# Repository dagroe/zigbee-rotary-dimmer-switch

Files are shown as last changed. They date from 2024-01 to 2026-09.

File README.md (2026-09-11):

# A rotary Zigbee dimmer switch
A Zigbee dimmer switch with a tactile feeling like classic rotary dimmers that seamlessly integrates with your existing switch and socket design lines (e.g. Gira System 55).

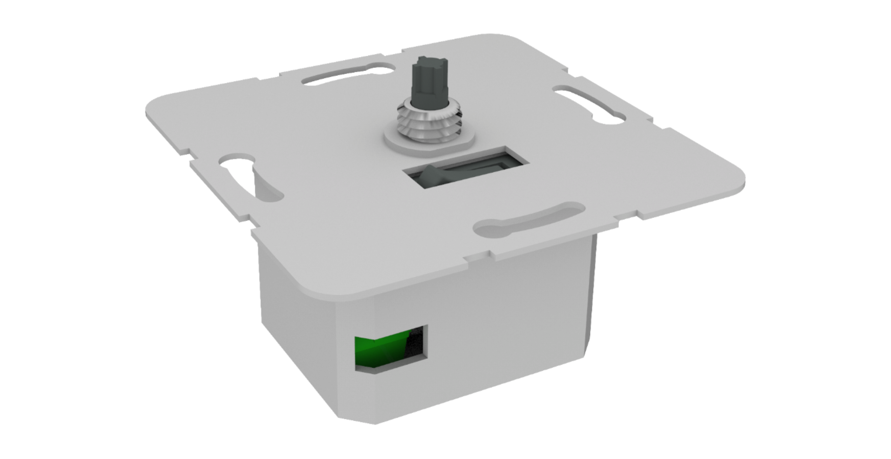
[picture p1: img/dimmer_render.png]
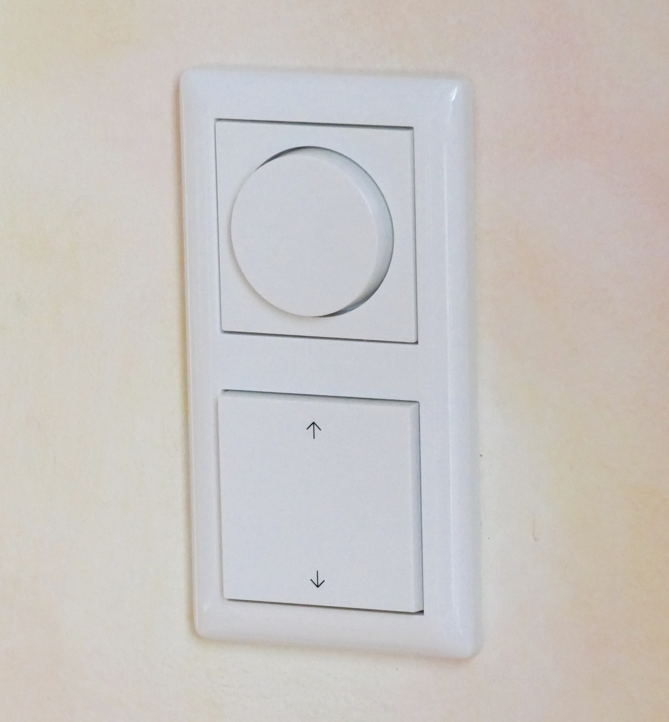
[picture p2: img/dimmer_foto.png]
|   |   |
|---|---|

## Use case, requirements, and features
The goal of this dimmer switch is to
* provide tactile feeling like classic rotary dimmers, i.e. rotate and push one big knob (instead of multiple buttons)
* integrate with existing switch and socket design lines (e.g. Gira System 55), also for multi frames
* offer an optional 230V (or 110V) power supply, no more changing batteries + acts as Zigbee router
* control existing smart lights (e.g. Philips Hue), not making classic bulbs smart (i.e. switching/dimming classic bulbs)

Also nice to have:
* be extendable, e.g. easily add multiple dimmer switches or push buttons in multi frames
* ✅ allow for a second rotary input by rotating the knob while pushing it (e.g. to change color temperature or scenes) — _implemented: push + rotate changes color temperature_
* ✅ feature an integrated 230V (or 110V) mechanical switch to switch power of the connected lamp socket (e.g. for emergencies or to reset the lamp when replacing classic wall switches) — _implemented: on-board relay + dedicated button_
* be affordable

## Backstory: Why yet _another_ Zigbee dimmer switch?
TL;DR; I couldn't find one to fit my use case, so I decided to build my own.

When I moved into my new home I already had many Philips Hue Bulbs and classic Hue dimmer switches (the on with the four buttons) to control the lights.
However, those didn't integrate well with my Gira System 55 outlets, switches, frames, etc. even when using fancy adapters (https://www.samotech.co.uk/products/philips-hue-dimmer-frame-cover-light-switch/)
And I was also a big fan of using a rotary knob for dimming lights, since it is just more convenient.

So why didn't I use available rotary zigbee dimmers? Basically all dimmers I found are "real" dimmers, in the sense that they expect to control a load (classic dimmable bulb) or simply don't fit into the 55mm Gira system.

Since I though "well, it can't be that hard to hook up a rotary encoder to a Zigbee chip", I set out to build a rotary dimmer switch myself.

## Current state of development
A working second prototype is built around the **ESP32-C6**. It joins any standard Zigbee coordinator (zigbee2mqtt, Home Assistant ZHA, deCONZ, …) as a mains-powered **Zigbee router** and controls bound smart lights with a single rotary knob. Hardware, firmware, and enclosure design files are all in this repository. It is a DIY prototype, not a finished product — see [Help wanted](#help-wanted).

### Hardware
- **ESP32-C6-MINI** module (Zigbee/Thread radio), programmed/powered over USB-C.
- Integrated **230V → 5V** power supply (IRM-02-5S) plus a 3.3V regulator — no batteries, and it acts as a Zigbee router.
- **Rotary encoder with push** (the single "big knob") for dimming and on/off.
- **WS2812B RGB LED** for status/feedback.
- On-board **230V relay** (on a normally-closed contact) to switch the connected lamp socket directly, with a dedicated button to toggle it.
- A separate commissioning button for pairing / factory reset.
- Two **external daughterboard ports** so the in-wall module can drive a second control surface: a port for an external rotary encoder (a second dimmer) and a port for a plain wall switch. Both are optional — when nothing is wired in they idle and stay unused.
- Designed to fit **Gira System 55** frames.

### Controls
| Input | Action |
| ----- | --- |
| Rotate knob | Brightness up / down (bound lights) |
| Push knob — short tap | Toggle on / off |
| Push knob — hold | Off |
| Push **and** rotate | Color temperature (warm / cool) |
| Relay button — tap | Cut / restore the 230V outlet (works even with no network) |
| External encoder (optional) | Second, independently bindable dimmer — same controls as the knob |
| External wall switch (optional) | Toggle on / off for its own independently bound light |
| Commission button — tap | Pair (start network steering) |
| Commission button — hold ~5 s | Factory reset (yellow warning while holding, red on reset) |

LED feedback: green = joined · solid red = not connected · white blink = command sent · red blink = command dropped (not joined) · blue blink = relay toggled · yellow = pairing / reset warning.

### Firmware
Built with **ESP-IDF** and the **esp-zigbee-sdk**. From `firmware/`:
```
idf.py set-target esp32c6
idf.py build
idf.py -p <PORT> flash monitor
```
After the first flash, firmware updates are delivered **over the air** (standard Zigbee OTA, with automatic rollback of a bad image). The single source of truth for the version is `firmware/main/version.h`.

### Repository layout
- `hardware/` — KiCad schematics, PCB, and exported gerbers/3D models.
- `firmware/` — ESP-IDF project ([`firmware/docs/OTA.md`](firmware/docs/OTA.md), [`firmware/z2m/README.md`](firmware/z2m/README.md), `firmware/TODO.md`).
- `enclosure/` — printable enclosure / knob design files.

## zigbee2mqtt integration & over-the-air updates
The dimmer joins any standard Zigbee coordinator and exposes four endpoints: the on-board **controller** (endpoint 1) that sends on/off, brightness and color commands to bound lights, the on-board **230V relay** (endpoint 2) to switch the connected lamp socket directly, and the two optional daughterboard ports — an **external encoder** (endpoint 3, a second dimmer) and an **external wall switch** (endpoint 4). Each controller endpoint is bound independently, so they act as separate controllers sharing one device card. It also implements the standard Zigbee OTA Upgrade cluster, so firmware updates are delivered over the air. To add the device to zigbee2mqtt and receive OTA updates from this repo, follow [`firmware/z2m/README.md`](firmware/z2m/README.md). Firmware-side OTA details (partitioning, rollback) are in [`firmware/docs/OTA.md`](firmware/docs/OTA.md).

## Help wanted
My prototype is working but I see a lot of potential for improvement. Since I am mostly a software engineer with limited knowledge of electronics, I am looking for other interested in taking this project further. You can find me on discord here: https://discord.gg/CjbDc5nPja or checkout the discussion here: https://community.home-assistant.io/t/diy-zigbee-rotary-wall-dimmer/681751

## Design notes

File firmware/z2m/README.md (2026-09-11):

# Using the dimmer with zigbee2mqtt (incl. OTA updates)

This folder is the zigbee2mqtt integration for the **DG Electronics ESP32-C6
rotary dimmer** (`ESP_DIMMER_1`):

| File | Purpose |
| ---- | --- |
| `ESP_DIMMER_1.js` | External converter — makes z2m recognize the device and enables OTA. |
| `ota-index.json` | OTA index served to z2m so it auto-discovers firmware updates. |
| `images/*.ota` | Published firmware images referenced by the index. |

The device speaks the **standard ZCL OTA Upgrade cluster**, so this also works
with ZHA/deCONZ — they just consume `ota-index.json` differently.

### What the device exposes

| Endpoint | Role | Use |
| --- | ---- | --- |
| 1 (`controller`) | on-board encoder/button: sends on/off, level (brightness) and color commands | Bind it to your light(s) via the device's **Bind** tab, or use the emitted commands in automations. |
| 2 (`relay`) | on/off **output** for the on-board 230V relay | Switch the connected lamp socket directly (e.g. emergency cut-off) from HA/z2m. |
| 3 (`ext_encoder`) | external encoder daughterboard: a **second dimmer** (on/off, level, color) | Bind it **independently** to a different light/group — so one in-wall module drives two dimmers. Unused if no board is connected. |
| 4 (`ext_switch`) | external **wall switch**: plain on/off (toggle) controller | Bind it independently to its own light/group. Unused if no switch is connected. |

> Endpoints 3 and 4 are always present. Because each endpoint is bound
> separately, the external encoder and switch act as independent controllers
> sharing the one device card — the closest a single Zigbee node gets to
> "separate devices". If nothing is wired to the daughterboard ports, those
> endpoints simply stay unbound and idle.

## Install (zigbee2mqtt users)

1. **Add the external converter.** Download
   [`ESP_DIMMER_1.js`](https://raw.githubusercontent.com/dagroe/zigbee-rotary-dimmer-switch/main/firmware/z2m/ESP_DIMMER_1.js)
   into your z2m **data directory** (next to `configuration.yaml`), and reference it:

   ```yaml
   external_converters:
     - ESP_DIMMER_1.js
   ```

2. **Enable OTA from this repo.** Point z2m at the hosted index — no download
   needed, z2m fetches it:

   ```yaml
   ota:
     zigbee_ota_override_index_location: https://raw.githubusercontent.com/dagroe/zigbee-rotary-dimmer-switch/main/firmware/z2m/ota-index.json
   ```

3. **Restart z2m.** The device now shows as *DG Electronics / ESP_DIMMER_1*, and
   the device's **OTA** tab will offer an update whenever a newer image is
   published here. (z2m checks on a schedule and the device also asks hourly;
   you can also click **Check for update** to force it.)

That's it — future firmware updates arrive over the air, no reflashing.

## Releasing a new firmware (maintainers)

The version lives only in `firmware/main/version.h`. To cut a release:

```bash
cd firmware

# 1. bump FW_VERSION_* in main/version.h, then build
idf.py build

# 2. package the image AND update the index in one step
python tools/make_ota.py \
    --in build/light_switch.bin \
    --out z2m/images/dimmer-<MAJOR.MINOR.PATCH>.ota \
    --index z2m/ota-index.json

# 3. commit the new image + index and push to main
git add z2m/images/dimmer-<MAJOR.MINOR.PATCH>.ota z2m/ota-index.json
git commit -m "OTA: release firmware <MAJOR.MINOR.PATCH>"
git push origin main
```

`make_ota.py` reads the version/manufacturer/image-type from the firmware
headers, computes `fileSize`/`sha512`, and rewrites the matching `ota-index.json`
entry with the raw-GitHub `url` for the new image. Once pushed to `main`, every
user's z2m discovers it automatically.

> The raw URLs above point at the **`main`** branch, so the integration only
> works once these files are merged to `main`.

See [`../docs/OTA.md`](../docs/OTA.md) for how the OTA client, partitioning, and
rollback work on the firmware side.

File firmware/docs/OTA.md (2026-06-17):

# Over-the-air firmware updates (Zigbee OTA)

The firmware implements the **standard ZCL OTA Upgrade cluster (0x0019)** as a
client. The device advertises a manufacturer code, image type, and the version
it is currently running; the coordinator (zigbee2mqtt, Home Assistant ZHA,
deCONZ, …) acts as the OTA server and pushes a matching `.ota` image. Nothing in
this is vendor-specific — any compliant coordinator can update the device.

## How matching works

A coordinator only offers an image when **all** of these hold:

| Field | Firmware source | Default |
| --- | --- | --- |
| Manufacturer code | `OTA_UPGRADE_MANUFACTURER` (`main/ota_driver.h`) | `0x131B` (4891)|
| Image type | `OTA_UPGRADE_IMAGE_TYPE` (`main/ota_driver.h`) | `0x1010` (4112)|
| File version | `FW_VERSION_*` (`main/version.h`) | `1.0.x` → `0x010000xx` |

The image's header manufacturer code + image type must equal the firmware's, and
its file version must be **greater** than the running version.

## Releasing an update

The version lives in exactly one place — `main/version.h` — and feeds the OTA
file version, the SW Build ID z2m shows, the ESP-IDF app version, and the `.ota`
the packaging script produces.

1. Bump `FW_VERSION_MAJOR/MINOR/PATCH` in `main/version.h` (e.g. `1.0.3` → `1.0.4`).
2. `idf.py build` — produces `build/light_switch.bin`.
3. Package the `.ota` (version/manufacturer/image-type are read from the headers,
   so no numbers to pass):

   ```
   python tools/make_ota.py --in build/light_switch.bin --out dimmer.ota
   ```

   The script prints the `fileVersion`, `fileSize`, and `sha512` to drop into the
   z2m index below.

## Serving it to zigbee2mqtt

Users install the device + auto-OTA by adding the external converter and the
hosted OTA index — see **[`../z2m/README.md`](../z2m/README.md)**. As a
maintainer you publish a release by pointing `make_ota.py` at `z2m/ota-index.json`
(it writes the image into `z2m/images/` and updates the index with the raw-GitHub
`url`), then commit + push to `main`; every user's z2m then discovers it.

For a quick local test without GitHub, you can instead point z2m's
`ota.zigbee_ota_override_index_location` at a local `ota-index.json` whose `url`
is a path z2m can read (in Docker, the in-container path), or use z2m's manual
"upload firmware" button to push a `.ota` directly.

## Rollback (auto-revert of a bad update)

App-rollback is enabled (`CONFIG_BOOTLOADER_APP_ROLLBACK_ENABLE`). A freshly
OTA'd image boots in *pending-verify* state and is only confirmed once the device
**rejoins the network** (`ota_confirm_running_image()` from the steering-success
signal). If the new image instead crashes or wedges before rejoining, the task
watchdog reboots it and the bootloader reverts to the previous working image. So
an update that bricks Zigbee self-heals without a site visit.

Implication for releases: the new firmware must be able to join the network, or
it will be rolled back. A normally-booted (UART-flashed) image is never in
pending-verify, so this is a no-op outside of OTA.

## First-time / verification notes

- On first OTA, watch the `OTA` log tag: `download started`, periodic writes, then
  `OTA complete (... bytes). Rebooting`. After reboot the device rejoins, logs
  `New OTA image confirmed healthy`, and reports the new `fileVersion`.
- To test rollback: build an image that deliberately fails to join, OTA it, and
  confirm the device reverts to the previous version after the watchdog reboot.
- The two app slots are `ota_0`/`ota_1` (1.5 MB each) from the dual-OTA partition
  table; an image must fit in one slot.

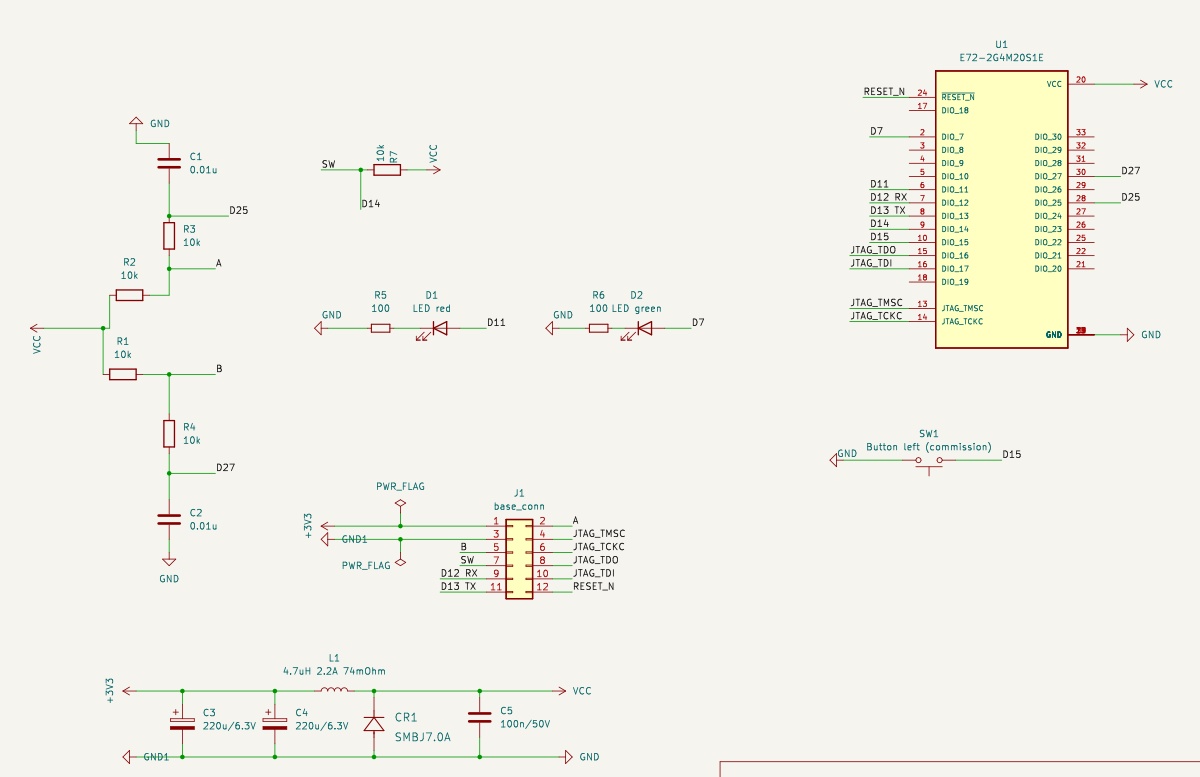
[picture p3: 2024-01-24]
img/dimmer_front_schematics.png

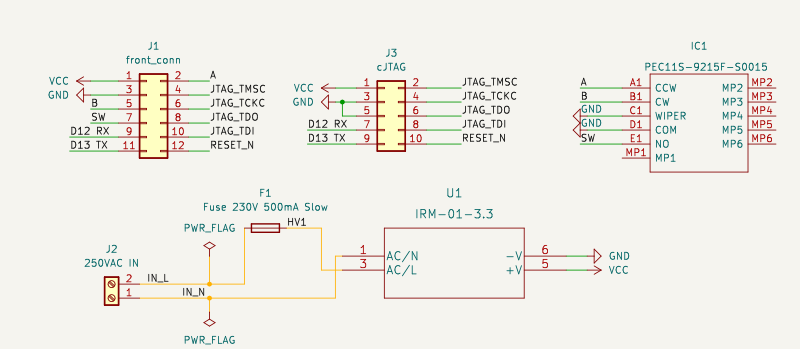
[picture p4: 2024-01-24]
img/dimmer_base_schematics.png

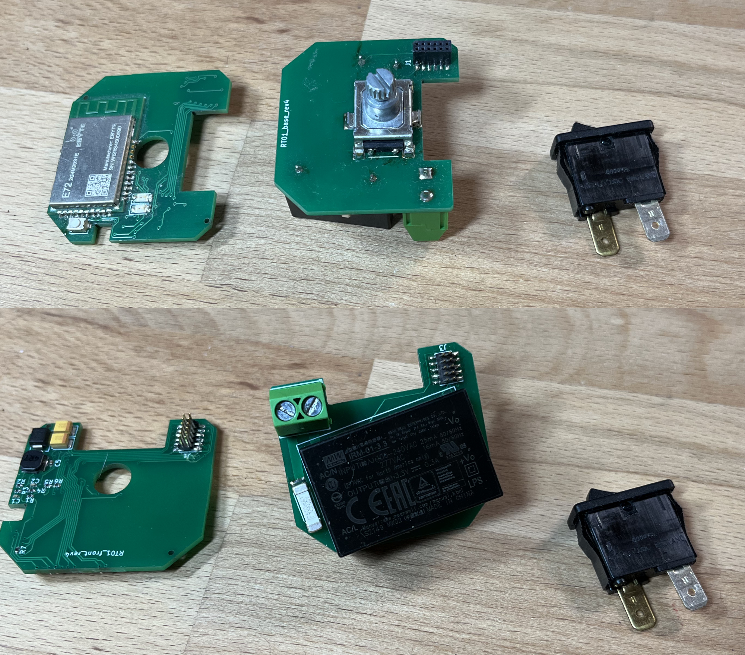
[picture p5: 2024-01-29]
img/dimmer_2.jpg

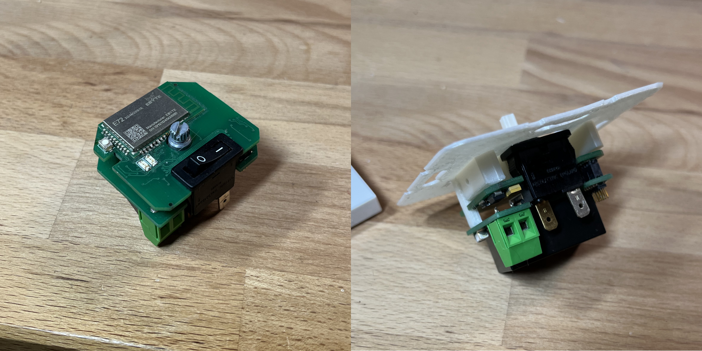
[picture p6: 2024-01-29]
img/dimmer_5.jpg

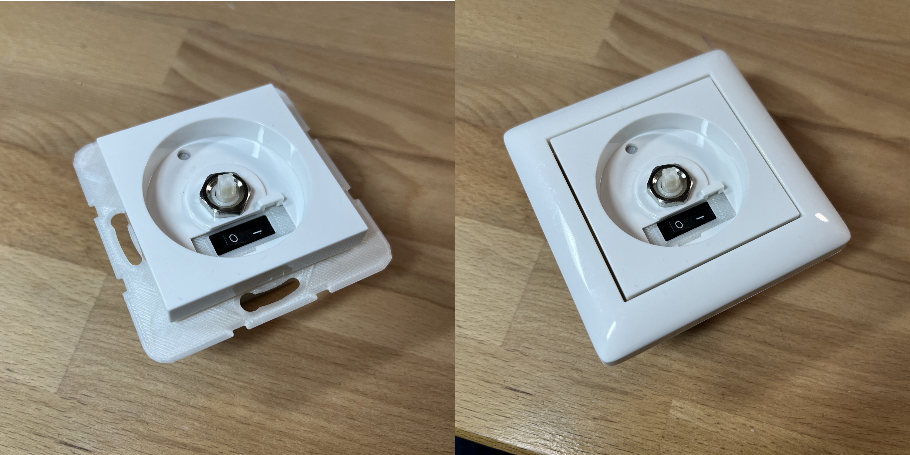
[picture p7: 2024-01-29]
img/dimmer_4.jpg

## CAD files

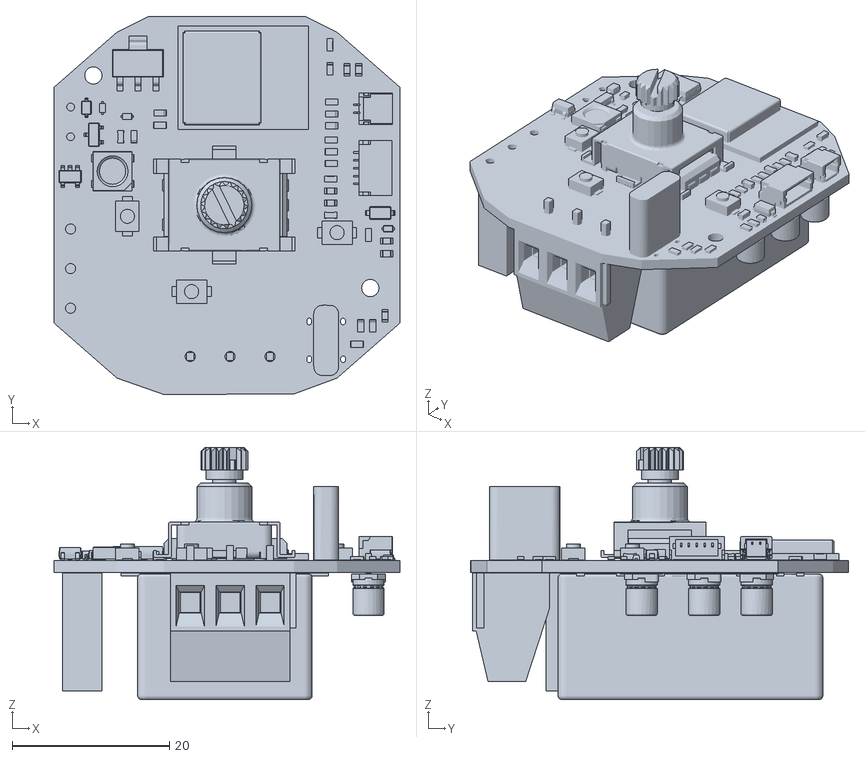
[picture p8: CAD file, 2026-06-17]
hardware/3d/dimmer_esp_v2_main.stl
44.0 x 48.1 x 32.1

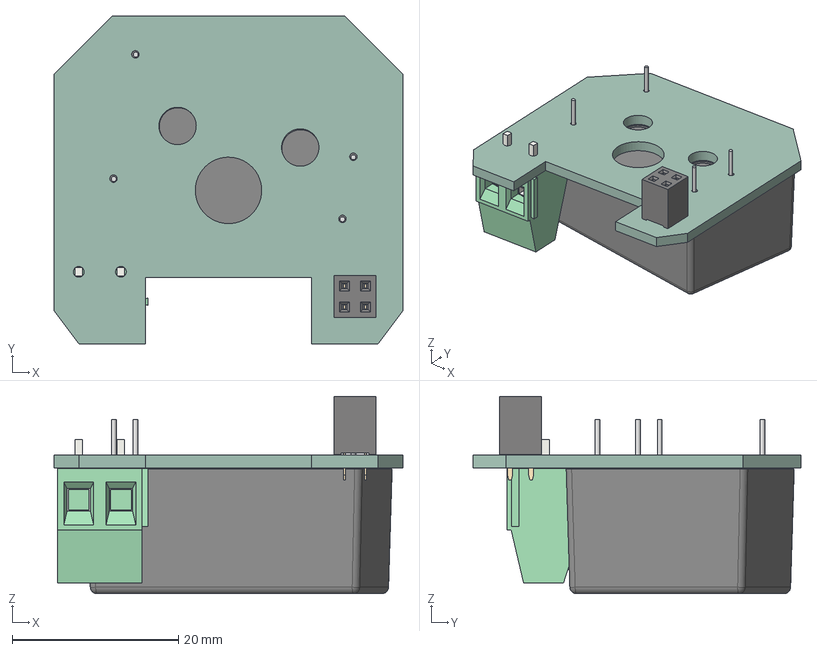
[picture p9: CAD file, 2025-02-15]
hardware/3d/dimmer_esp_v1_4_power230.step
42.0 x 39.5 x 23.8 mm
PinSocket_2x02_P254mm_Vertical
TerminalBlock_Phoenix_MKDS_15_2_508_1x02_P508mm_Horizontal
ASSEMBLY
IRM-01-5
dimmer_esp_v1_power230_PCB

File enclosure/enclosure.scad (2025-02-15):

$fa = 1;
$fs = 0.2;



make_shaft = true;
make_base_plate = true;
make_spacer = true;
make_middle_spacer = true;
build_bottom_shell = true;
render_top_pcb = false;
render_bottom_pcb = false;

include <BOSL2/std.scad>
include <BOSL2/threading.scad>

// function for rounded rectangle
module make_rounded_rectangle(width, height, radius) {
    hull() {
        translate([radius,radius,0]) circle(radius);
        translate([width-radius,radius,0]) circle(radius);
        translate([width-radius,height-radius,0]) circle(radius);
        translate([radius,height-radius,0]) circle(radius);
    }
}

// main function to make front facing plate with thread/bushing
module base_plate(thickness, width_and_depth, corner_radius, offset_z) {
    // make cutouts into plate

    // make for holes with circular slits to attach base plate to wall socket
    // prepare rectangular cutouts on border (will be rotated to four sides along other holes)
    cutout_depth_x = 1.5;
    cutout_width_y = 4.15;
    cutout_offset_y = 19.8;

    distance_from_border = 3.7;
    length_hole_in_arc_degree = 25;
    width_hole = 3.7;
    width_bigger_hole = 5.5;
    arc_offset = width_hole * 0.5;

    radius_circle = width_and_depth*0.5 - distance_from_border - arc_offset;

    difference(){
        // make solid plate first
        linear_extrude(height=thickness) translate([-width_and_depth*0.5, -width_and_depth*0.5, 0]) make_rounded_rectangle(width_and_depth, width_and_depth, corner_radius);

        // make cutouts on 4 sides
        for (i=[0:1:4]) {
            center = i * 360 / 4;

            // holes for screws
            rotate([0, 0, center-length_hole_in_arc_degree/2]) rotate_extrude(angle=length_hole_in_arc_degree,convexity = 10) translate([radius_circle, 0,0]) square(width_hole, center=true);
            rotate([0, 0, center+length_hole_in_arc_degree/2]) linear_extrude(5, center=true) translate([radius_circle, 0, 0]) circle(d=width_bigger_hole);
            rotate([0, 0, center-length_hole_in_arc_degree/2]) linear_extrude(5, center=true) translate([radius_circle, 0, 0]) circle(d=width_hole);

            // hole markers on sides
            rotate([0, 0, center]) translate([width_and_depth*0.5 - cutout_depth_x, cutout_offset_y*0.5+cutout_width_y*0.5, 0]) translate([0, -cutout_width_y*0.5, 0]) linear_extrude(20, center=true) square([cutout_depth_x, cutout_width_y]);
            rotate([0, 0, center]) translate([width_and_depth*0.5 - cutout_depth_x, -(cutout_offset_y*0.5+cutout_width_y*0.5), 0]) translate([0, -cutout_width_y*0.5, 0]) linear_extrude(20, center=true) square([cutout_depth_x, cutout_width_y]);

        }

        // cutout rectangle for switch
        switch_cutout_width = 18.0;
        switch_cutout_depth = 7.0;
        switch_cutout_offset_y = -16.2;
        translate([0, switch_cutout_offset_y, 0]) linear_extrude(thickness+2, center=true) square([switch_cutout_width, switch_cutout_depth], center=true);
    }
}


// make custom shaft
shaft_length_encoder_connector = 8;
shaft_length_below_button_disc = 5.6;
// TOD add offset for disc from bottom / split bottom into half-shaft connector and full-shaft
shaft_length_top = 20;
shaft_length = shaft_length_encoder_connector + shaft_length_below_button_disc + shaft_length_top;
shaft_diameter_top = 4.0;
shaft_radius_top = shaft_diameter_top/2;
shaft_diameter_encoder_connector = 3.1;
shaft_radius_encoder_connector = shaft_diameter_encoder_connector/2;
shaft_encoder_connector_cut_offset_y = 0.3;

disc_height = 1;
disc_diameter = 6;
disc_radius = disc_diameter/2;

shaft_4mm_part_length = shaft_length_below_button_disc + shaft_length_top;


if(make_shaft) {

translate([0,0,0]) color([1,0,0]) union() {
    // make top shaft part (4mm diameter)
    translate([0,0,shaft_length_encoder_connector+shaft_4mm_part_length/2]) cylinder(h=shaft_4mm_part_length, r=shaft_radius_top, center=true);
    // make disc that pushes on the button
    translate([0,0,shaft_length_encoder_connector+shaft_length_below_button_disc+(disc_height/2)]) cylinder(h=disc_height, r=disc_radius, center=true);
    // make encoder connector (cut off half the shaft for "D" shape)
    difference() {
        translate([0,0,shaft_length_encoder_connector/2]) cylinder(h=shaft_length_encoder_connector, r=shaft_radius_encoder_connector, center=true);
        translate([-(shaft_radius_encoder_connector+1), shaft_encoder_connector_cut_offset_y, -1]) cube([shaft_diameter_encoder_connector+2, shaft_radius_encoder_connector+1, shaft_length_encoder_connector+2]);
    }
}
}

flap_thickness = 0.8;

spacer_height = 2.6 + flap_thickness; //2.6
cutter_height = spacer_height + 2;


// make spacer between base plate and top pcb that also stabilizes the push ring
if(make_spacer) {
    translate([0,0,10.2]) color([0,0,1]) {
        union() {
        difference() {
            // base rectangle
            translate([0,4,0]) linear_extrude(height=spacer_height) square([29.6,25], center=true);
            // subtract first hole for encoder clamp
            translate([6,0,cutter_height/2-1]) cylinder(h=cutter_height, r=1.5, center=true);
            // subtract second for encoder clamp
            translate([-6,0,cutter_height/2-1]) cylinder(h=cutter_height, r=1.5, center=true);
            // subtract cutout for push disc
            //translate([0,0,cutter_height/2+1.8]) cylinder(h=cutter_height, r=11/2, center=true);
            // subtract cutout for button
            translate([0,4,-0.5]) linear_extrude(height=cutter_height) square([9.8,5], center=true);
            // subtract cutout for LED
            translate([-12,4.7,-0.5]) linear_extrude(height=cutter_height) square([8,8], center=true);
            // subtract cutout for buttons
            translate([-10,14.5,-0.5]) linear_extrude(height=cutter_height) square([14,12], center=true);
            // flap cutout
            translate([0,0,-1]) linear_extrude(height=spacer_height+2) square([9.8,12], center=true);
            // holes for encoder pins
            translate([0,-7.5,0]) cylinder(h=4, r=1, center=true);
            translate([0,-8.5,-2]) linear_extrude(height=4) square([2,2], center=true);
            translate([-2.54,-7.5,0]) cylinder(h=4, r=1, center=true);
            translate([-2.54,-8.5,-2]) linear_extrude(height=4) square([2,2], center=true);
            translate([2.54,-7.5,0]) cylinder(h=4, r=1, center=true);
            translate([2.54,-8.5,-2]) linear_extrude(height=4) square([2,2], center=true);
        }
        difference() {
            // make "flap"
            translate([0,-1,spacer_height-flap_thickness]) linear_extrude(height=flap_thickness) square([8.8,13.8], center=true);
            // subtract hole for shaft
            translate([0,0,cutter_height/2-1]) cylinder(h=cutter_height, r=shaft_radius_top+0.2, center=true);
        }
        // make pusher on flap
        translate([0,4,spacer_height-flap_thickness-0.2]) linear_extrude(height=0.2) square([5,3], center=true);
       
        }
    }
    
}
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

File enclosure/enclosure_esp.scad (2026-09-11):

$fa = 1;
$fs = 0.2;
$fn=64;



make_shaft = false;
make_base_plate = true;
make_base_plate_thread = false;
make_thread = true;
make_spacer = true;
make_middle_spacer = true;
build_bottom_shell = false;
render_pcb = false;

include <BOSL2/std.scad>
include <BOSL2/threading.scad>

//translate([0.3,-0.8,0]) import(file="esp_edge_cuts3.svg",center=true);

/*
points = [
[181.5000,39.0000],
[189.5000,46.0000],
[189.5000,76.0000],
[181.5000,83.0000],
[172.0000,86.5000],
[163.5000,86.5000],
[153.5000,83.0000],
[145.5000,76.0000],
[145.5000,46.0000],
[153.5000,39.0000],
[157.5000,37.0000],
[177.5000,37.0000]
];

paths = [[0,1,2,3,4,5,6,7,8,9,10,11,0]];

difference() {
translate([-180,0,0]) linear_extrude(20) offset(1) polygon(points=points, paths=paths);
translate([-180,0,-1]) linear_extrude(22) polygon(points=points, paths=paths);
}
*/

module my_model() {

    // function for rounded rectangle
    module make_rounded_rectangle(width, height, radius) {
        hull() {
            translate([radius,radius,0]) circle(radius);
            translate([width-radius,radius,0]) circle(radius);
            translate([width-radius,height-radius,0]) circle(radius);
            translate([radius,height-radius,0]) circle(radius);
        }
    }

    // main function to make front facing plate with thread/bushing
    module base_plate(thickness, width_and_depth, corner_radius, offset_z) {
        // make cutouts into plate

        // make for holes with circular slits to attach base plate to wall socket
        // prepare rectangular cutouts on border (will be rotated to four sides along other holes)
        cutout_depth_x = 1.5;
        cutout_width_y = 4.15;
        cutout_offset_y = 19.8;

        distance_from_border = 3.7;
        length_hole_in_arc_degree = 25;
        width_hole = 3.7;
        width_bigger_hole = 5.5;
        arc_offset = width_hole * 0.5;

        radius_circle = width_and_depth*0.5 - distance_from_border - arc_offset;

        difference(){
            // make solid plate first
            linear_extrude(height=thickness) translate([-width_and_depth*0.5, -width_and_depth*0.5, 0]) make_rounded_rectangle(width_and_depth, width_and_depth, corner_radius);

            // make cutouts on 4 sides
            for (i=[0:1:4]) {
                center = i * 360 / 4;

                // holes for screws
                rotate([0, 0, center-length_hole_in_arc_degree/2]) rotate_extrude(angle=length_hole_in_arc_degree,convexity = 10) translate([radius_circle, 0,0]) square(width_hole, center=true);
                rotate([0, 0, center+length_hole_in_arc_degree/2]) linear_extrude(5, center=true) translate([radius_circle, 0, 0]) circle(d=width_bigger_hole);
                rotate([0, 0, center-length_hole_in_arc_degree/2]) linear_extrude(5, center=true) translate([radius_circle, 0, 0]) circle(d=width_hole);

                // hole markers on sides
                rotate([0, 0, center]) translate([width_and_depth*0.5 - cutout_depth_x, cutout_offset_y*0.5+cutout_width_y*0.5, 0]) translate([0, -cutout_width_y*0.5, 0]) linear_extrude(20, center=true) square([cutout_depth_x, cutout_width_y]);
                rotate([0, 0, center]) translate([width_and_depth*0.5 - cutout_depth_x, -(cutout_offset_y*0.5+cutout_width_y*0.5), 0]) translate([0, -cutout_width_y*0.5, 0]) linear_extrude(20, center=true) square([cutout_depth_x, cutout_width_y]);

            }
        }
    }

    // socket adapter
    module SocketAdapter(side_thickness=1.0, shaft_radius=3.0, offset_z=0) {

        // ----- Parameters -----
        top_thickness       = 0.5;
        groove_margin       = 0.10;
        height              = 4 + 0.2; // knob height + margin
        thread_tunnel_margin= 0.2;
        thread_tunnel_length= 3.5;
        dial_connector_length = 4.2;
        margin_from_knob    = 0.2;
        overlap_bottom      = 0.1;
        knob_radius         = 3.0;

        // ----- Inner cutout -----
        module knob_socket_make_inner_cutout(knob_radius, margin_from_knob, height) {
            outer_r = knob_radius + margin_from_knob;
            inner_r = outer_r - 0.5;
            n = 36; // 2*18
            pts = [
                for (i = [0:n-1]) 
                    let (a = 360/n * i)
                    [(i % 2 == 0 ? inner_r : outer_r) * cos(a),
                     (i % 2 == 0 ? inner_r : outer_r) * sin(a)]
            ];
            linear_extrude(height)
                polygon(points=pts);
        }

        // ----- Outer shell -----
        module knob_socket_make_outer_shell(knob_radius, side_thickness, top_thickness, height) {
            difference() {
                cylinder(r=knob_radius+side_thickness, h=height+top_thickness, $fn=72);
            }
        }

        // ----- Groove -----
        module knob_socket_make_groove(shaft_radius, groove_width, groove_height, height) {
            width = shaft_radius*2-0.2;
            translate([-width/2, -groove_width/2, height-groove_height])
                cube([width, groove_width, groove_height], center=false);
        }

        // ----- Knob socket -----
        module make_knob_socket(knob_radius, shaft_radius, margin_from_knob, side_thickness, top_thickness, groove_margin, height) {
            groove_width  = 1 - groove_margin;
            groove_height = 1.6;
            
            union() {
                difference() {
                    knob_socket_make_outer_shell(knob_radius, side_thickness, top_thickness, height);
                    translate([0,0, -1]) knob_socket_make_inner_cutout(knob_radius, margin_from_knob, height + 1);
                }
                knob_socket_make_groove(shaft_radius, groove_width, groove_height, height);
            }
            
        }

        // ----- Shaft -----
        module make_shaft(height, top_thickness, shaft_radius, thread_tunnel_length, dial_connector_length, overlap_bottom) {
            overlap_top = 0.5;

            // Cross boxes
            box_width = 1;
            box_height = dial_connector_length+overlap_top;
            
            middle_radius = shaft_radius;

            union() {
                translate([0,0,-overlap_bottom]) cylinder(h=thread_tunnel_length+overlap_top+overlap_bottom, r=middle_radius);
                translate([0,0,thread_tunnel_length])
                union() {
                    translate([0,0,box_height/2]) cube([box_width, middle_radius*2 - 0.1, box_height], center=true);
                    translate([0,0,box_height/2]) cube([middle_radius*2 - 0.1, box_width, box_height], center=true);
                    cylinder(r=2.05, h=dial_connector_length+overlap_top);
               };
            }
            
        }
        


        // ----- Build adapter -----
        translate([0,0, offset_z - (height + top_thickness)])
            union() {
                make_knob_socket(knob_radius, shaft_radius, margin_from_knob, side_thickness, top_thickness, groove_margin, height);
                translate([0,0,height+top_thickness-overlap_bottom])
                     make_shaft(height, top_thickness, shaft_radius, thread_tunnel_length, dial_connector_length, overlap_bottom);
            }
            
    }

    pcb_outline_svg_offset_x = 0.3;
    pcb_outline_svg_offset_y = -0.8;

    side_thickness = 0.9;
        
    // socket adapter, thread tunnel cutout, and spacer
    shaft_diameter = 6.0;
    shaft_radius = shaft_diameter / 2;

    offset_z = 2;

    if (make_shaft) {
        color([1,0,0]) translate([0,0,-1.5]) SocketAdapter(side_thickness, shaft_radius, offset_z);
        
    }


    // base plate parameters
    base_plate_thickness = 1.6;
    base_plate_width_and_depth = 71.0;
    base_plate_corner_radius = 6.0;



    //shell_height = shell_bottom_thickness + space_at_bottom_of_shell + height_of_pcb_components_bottom + bottom_pcb_thickness + height_of_pcb_components_middle + top_pcb_thickness + space_between_top_pcb_and_base_plate;

    offset_base_plate = 0;//shell_height - shell_bottom_thickness - base_plate_thickness;

    top_rod_height = 7;

    reinforcement_ring_diameter = 14;
    reinforcement_ring_radius = reinforcement_ring_diameter / 2;
    reinforcement_ring_height = 1.2;

    base_plate_offset_z = -7;//13.6;


    //color([1,0,0]) translate([0,0,5]) cylinder(h=20, r=2.9, center=true);

    // shaft adapter
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

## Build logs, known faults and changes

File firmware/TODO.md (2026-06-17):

# Firmware TODO

Deferred robustness/maintainability items from the wall-install review.
Items are roughly in priority order.

## Smaller follow-ups

- [ ] **Re-add network-loss self-heal, safely.** A first attempt (re-steer on
  ESP_ZB_ZDO_SIGNAL_LEAVE / NO_ACTIVE_LINKS_LEFT) was reverted: it raced the
  stack's own commissioning/leave state machine — it broke initial joins
  (leave-with-rejoin during commissioning) and asserted in `zdo_app.c` during a
  coordinator-forced leave-reset while steering was retrying. The stack already
  auto-rejoins routers on transient loss. If re-added, prefer a clean
  `esp_restart()` on a RESET-type leave (let the device come up factory-new)
  rather than calling commissioning APIs from the leave handler, and test
  against a coordinator that actively removes the device.

- [ ] **Handle LED-strip init failure more gracefully.** If
  `led_strip_new_rmt_device` fails, `led_task` is never started and nothing
  drains `led_evt_queue`; senders use timeout 0 so it is harmless, but the
  device then runs with no status LED.

## Done (wall-install review, this branch)

- [x] Move commission button off strapping pin GPIO9 → GPIO23 (board rewired + firmware)
- [x] Move relay driver off strapping pin GPIO15 → GPIO2 (board rewired; not yet driven by firmware)
- [x] Lock cross-task Zigbee stack calls (fixes vPortExitCritical freeze)
- [x] Reboot on critical init failure instead of hanging
- [x] Bound the Zigbee stack-lock wait so UI tasks can't wedge
- [x] Enable task-watchdog panic for self-recovery on hang
- [x] Raise Zigbee task priority/stack
- [x] Keep GPIO ISRs in IRAM (no dropped edges during flash writes)
- [x] Debounce only the active button's interrupt
- [x] 4MB flash + dual-OTA partition layout
- [x] Standard Zigbee OTA Upgrade client (download/apply; see `docs/OTA.md`)
- [x] OTA rollback: image confirmed only after rejoining the network, else
      auto-reverts to the previous image
- [x] Single-source firmware version (`main/version.h`) feeding OTA version,
      SW Build ID, app version, and the .ota packaging tool
- [x] Suppress outbound commands when not joined; LED feedback on every command
      (white = sent, red = dropped/not joined)
- [x] Relay: NC inversion fix, local GPIO18 button, and configurable
      power_on_behavior (StartUpOnOff, NVS-persisted)
- [x] UX: push-rotate = color temperature; factory-reset warning; knob-push
      hold dead-zone fix

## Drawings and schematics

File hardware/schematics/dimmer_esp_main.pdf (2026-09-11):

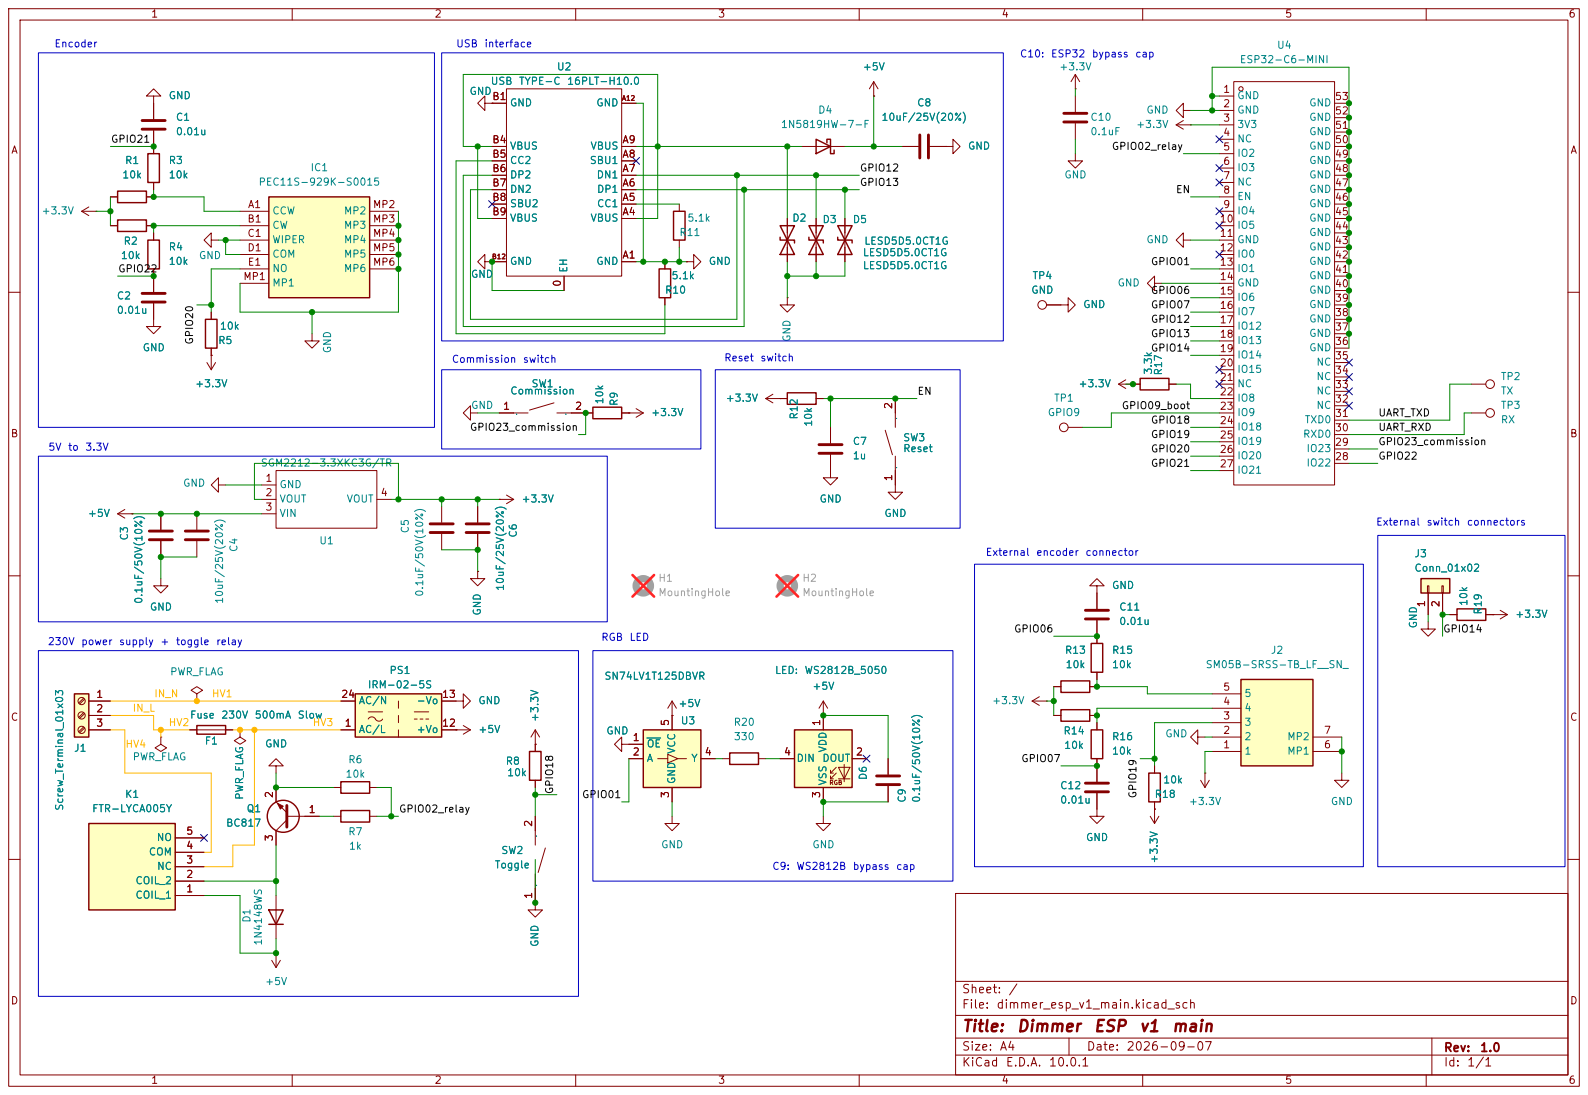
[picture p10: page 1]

VBUS A4 CC1 A5 DP1 A6 DN1 A7 SBU1 A8 VBUS A9 GND A12 GND B1

External switch connectors C9: WS2812B bypass cap RGB LED

230V power supply + toggle relay

Sheet: /
File: dimmer_esp_v1_main.kicad_sch
Title: Dimmer ESP v1 main

Size: A4 | Rev: 1.0
KiCad E.D.A. 10.0.1 | Id: 1/1

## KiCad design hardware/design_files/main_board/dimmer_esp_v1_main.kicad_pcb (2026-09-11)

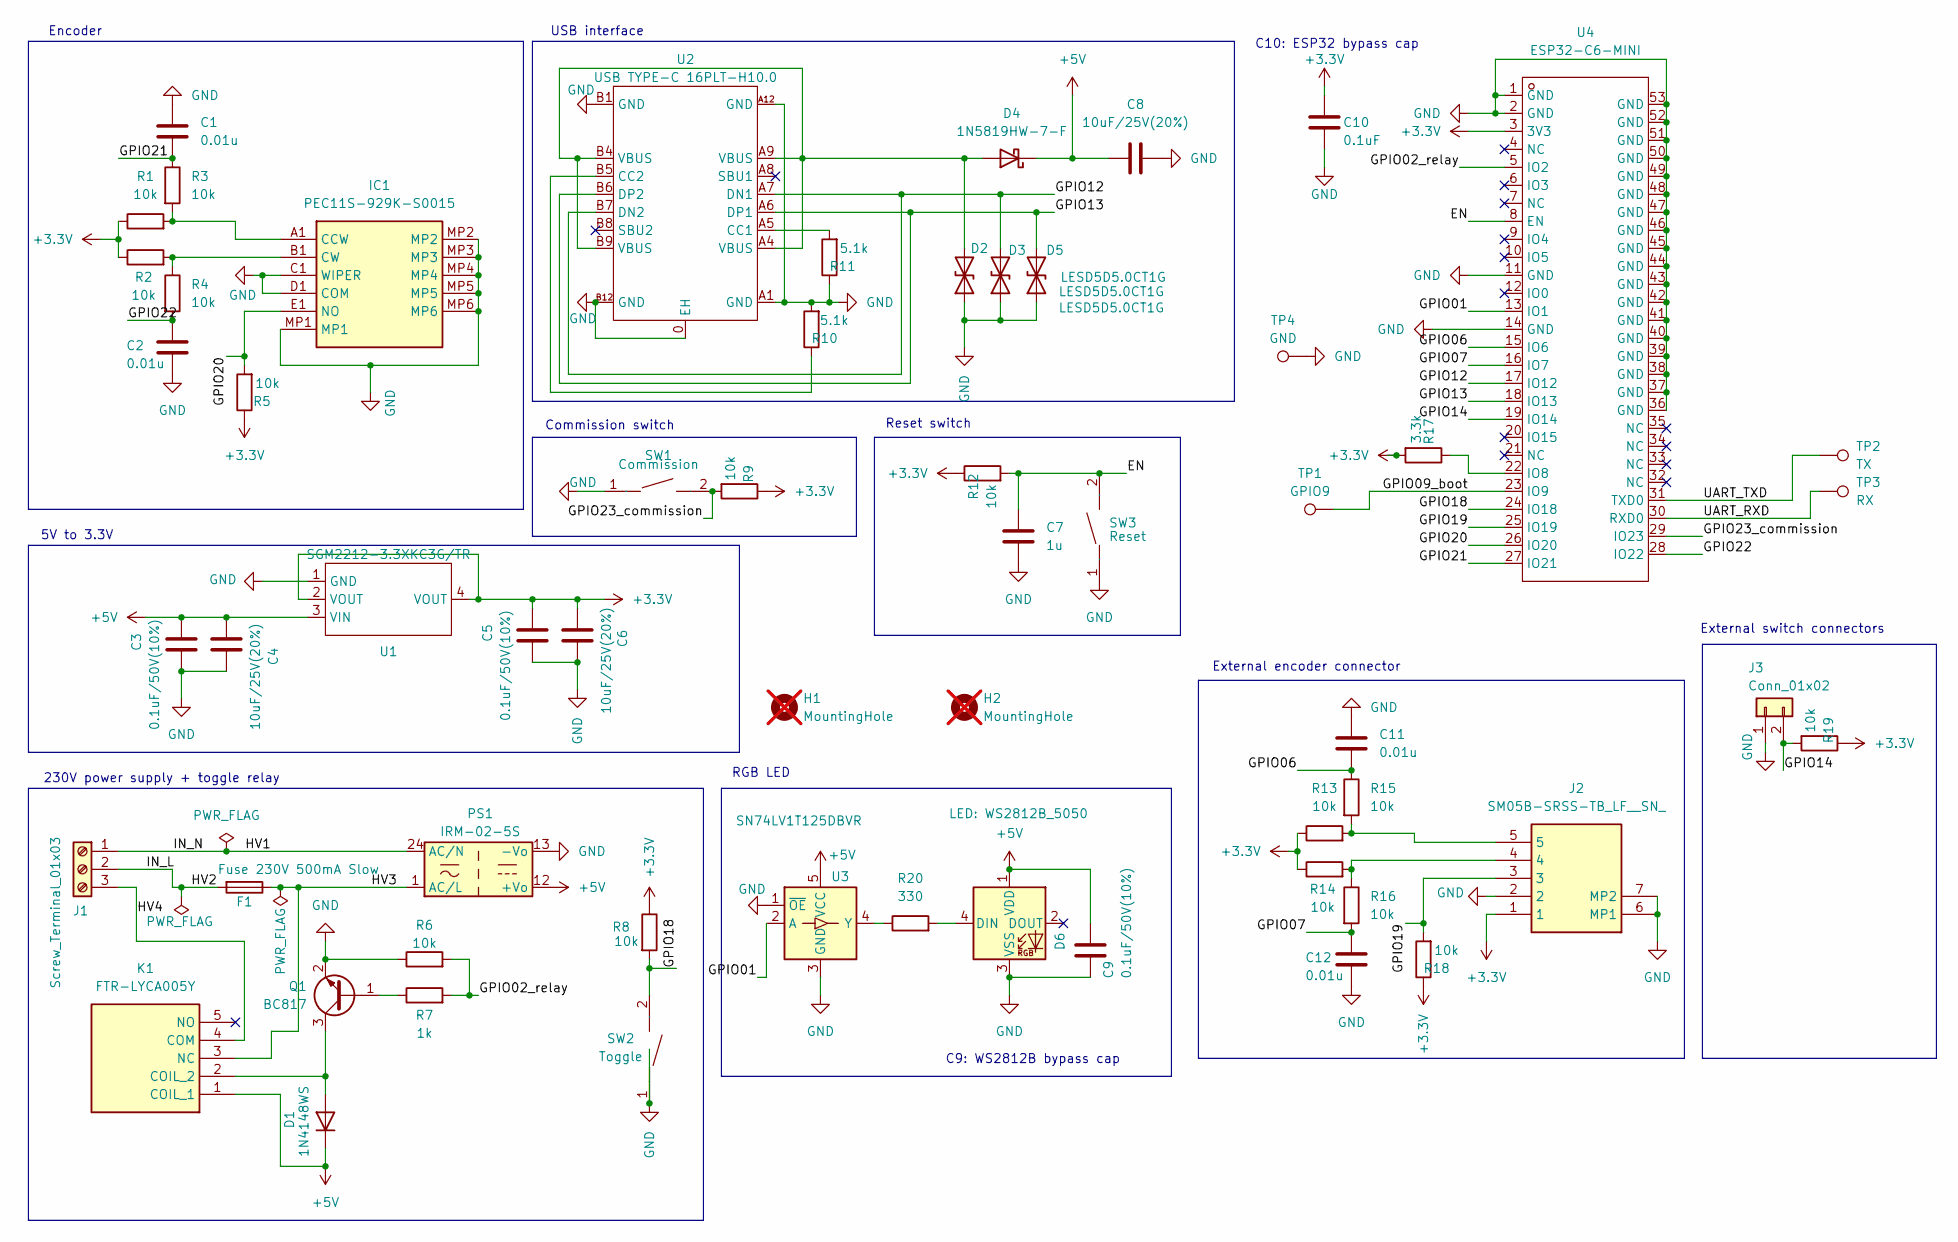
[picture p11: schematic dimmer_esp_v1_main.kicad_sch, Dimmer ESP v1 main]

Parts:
C1, C2, C11, C12: 0.01u; C_0603_1608Metric; MPN 0603B103K500NT; LCSC C57112
C3, C5: 0.1uF/50V(10%); C_0603_1608Metric; MPN CT41G-0603-2X1-50V-0.1uF-K(N); LCSC C125205
C4, C6, C8: 10uF/25V(20%); C_Elec_4x5.4; MPN MVK25V10M4*5 4.0TP; LCSC C371122
C7: 1u; C_0603_1608Metric; MPN CL10A105KB8NNNC; LCSC C15849
C9: 0.1uF/50V(10%); C_0603_1608Metric; LCSC C125205
C10: 0.1uF; C_0603_1608Metric; MPN CC0603KRX7R9BB104; LCSC C14663
D1: 1N4148WS; D_SOD-323; MPN 1N4148WS; LCSC C2128
D2, D3, D5: LESD5D5.0CT1G; D_SOD-523; MPN BNLESD5D5.0CT1G; LCSC C20416613
D4: 1N5819HW-7-F; D_SOD-123; MPN 1N5819HW-7-F; LCSC C82544
D6: LED: WS2812B_5050; LED_WS2812B_PLCC4_5.0x5.0mm_P3.2mm; MPN XL-5050RGBC-2812B; LCSC C2843785
F1: Fuse 230V 500mA Slow; 0443.500DR; MPN 0443.500DR; LCSC C315874
H1, H2: MountingHole; MountingHole_2.2mm_M2_DIN965; not fitted
IC1: PEC11S-929K-S0015; PEC11S929KS0015; Mouser Part Number 652-PEC11S929K-S0015
J1: Screw_Terminal_01x03; TerminalBlock_Phoenix_MKDS-1,5-3-5.08_1x03_P5.08mm_Horizont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; MPN 1715734; LCSC C480520
J2: SM05B-SRSS-TB_LF__SN_; JST_SH_SM05B-SRSS-TB_1x05-1MP_P1.00mm_Horizontal; Manufacturer_Part_Number SM05B-SRSS-TB(LF)(SN); LCSC C136657
J3: Conn_01x02; JST_SH_SM02B-SRSS-TB_1x02-1MP_P1.00mm_Horizontal; MPN SM02B-SRSS-TB(LF)(SN); LCSC C160402
K1: FTR-LYCA005Y; FTRLYCA024Y; Mouser Part Number 817-FTR-LYCA005Y
PS1: IRM-02-5S; Converter_ACDC_MeanWell_IRM-02-xx_SMD; MPN IRM-02-5S; LCSC C7211217
Q1: BC817; SOT-23; MPN BC817-40,215; LCSC C52801
R1, R2, R3, R4, R5, R6, R8, R9, R12, R13, R14, R15, R16, R18, R19: 10k; R_0603_1608Metric; MPN 0603WAF1002T5E; LCSC C25804
R7: 1k; R_0603_1608Metric; MPN 0603WAF1001T5E; LCSC C21190
R10, R11: 5.1k; R_0603_1608Metric; MPN 0603WAF5101T5E; LCSC C23186
R17: 3.3k; R_0603_1608Metric; MPN 0603WAF3301T5E; LCSC C22978
R20: 330; R_0603_1608Metric; MPN 0603WAF3300T5E; LCSC C23138
SW1: Commission; SW-SMD_L3.9-W3.0-P4.45; Manufacturer Part TS-1088-AR02016; LCSC Part Name 4*3*2mm 立贴 轻触开关
SW2: Toggle; SW-SMD_L3.9-W3.0-P4.45; Manufacturer Part TS-1088-AR02016; LCSC Part Name 4*3*2mm 立贴 轻触开关
SW3: Reset; SW-SMD_L3.9-W3.0-P4.45; Manufacturer Part TS-1088-AR02016; LCSC Part Name 4*3*2mm 立贴 轻触开关
TP1: GPIO9; TestPoint_Pad_D1.5mm
TP2: TX; TestPoint_Pad_D1.5mm
TP3: RX; TestPoint_Pad_D1.5mm
TP4: GND; TestPoint_Pad_D1.5mm
U1: SGM2212-3.3XKC3G/TR; SOT-223-3_L6.5-W3.4-P2.30-LS7.0-BR; Manufacturer Part SGM2212-3.3XKC3G/TR; LCSC Part Name SGM2212-3.3XKC3G/TR
U2: USB TYPE-C 16PLT-H10.0; TYPE-C-SMD_USB4120-03-C; Manufacturer Part TYPE-C 16PLT-H10.0; LCSC Part Name Type-C 母 立贴
U3: SN74LV1T125DBVR; SOT-23-5; MPN SN74LV1T125DBVR; LCSC C473338
U4: ESP32-C6-MINI; WIFIM-SMD_61P-L16.6-W13.2-P0.80-ESP32-C6-MINI-1-N4; Manufacturer Part ESP32-C6-MINI-1-N4; LCSC Part Name ESP32-C6-MINI-1-N4

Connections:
+3.3V: C5.2, C6.1, C10.1, J2.1, R1.1, R2.1, R5.1, R8.1, R9.1, R12.1, R13.1, R14.1, R17.2, R18.1, R19.1, U1.2 (VOUT), U1.4 (VOUT), U4.3 (3V3)
+5V: C3.2, C4.1, C8.1, C9.1, D1.1 (K), D4.1 (K), D6.1 (VDD), K1.1 (COIL_1), PS1.12 (+Vo), U1.3 (VIN), U3.5 (VCC)
/EN: C7.2, R12.2, SW3.2, U4.8 (EN)
/GPIO01: U3.2 (A), U4.13 (IO1)
/GPIO02_relay: R6.2, R7.2, U4.5 (IO2)
/GPIO06: C11.2, R15.1, U4.15 (IO6)
/GPIO07: C12.2, R16.2, U4.16 (IO7)
/GPIO09_boot: TP1.1 (1_1), U4.23 (IO9)
/GPIO12: D3.2 (A2), U2.A7 (DN1), U2.B7 (DN2), U4.17 (IO12)
/GPIO13: D5.2 (A2), U2.A6 (DP1), U2.B6 (DP2), U4.18 (IO13)
/GPIO14: J3.2, R19.2, U4.19 (IO14)
/GPIO18: R8.2, SW2.2, U4.24 (IO18)
/GPIO19: J2.3, R18.2, U4.25 (IO19)
/GPIO20: IC1.E1 (NO), R5.2, U4.26 (IO20)
/GPIO21: C1.2, R3.1, U4.27 (IO21)
/GPIO22: C2.2, R4.2, U4.28 (IO22)
/GPIO23_commission: R9.2, SW1.2, U4.29 (IO23)
/HV1: J1.1, PS1.24 (AC/N)
/HV2: F1.2, J1.2
/HV3: F1.1, K1.3 (NC), PS1.1 (AC/L)
/HV4: J1.3, K1.4 (COM)
/UART_RXD: TP3.1 (1_1), U4.30 (RXD0)
/UART_TXD: TP2.1 (1_1), U4.31 (TXD0)
GND: C1.1, C2.1, C3.1, C4.2, C5.1, C6.2, C7.1, C8.2, C9.2, C10.2, C11.1, C12.1, D2.1 (A1), D3.1 (A1), D5.1 (A1), D6.3 (VSS), IC1.C1 (WIPER), IC1.D1 (COM), IC1.MP1, IC1.MP2, IC1.MP3, IC1.MP4, IC1.MP5, IC1.MP6, J2.2, J2.6 (MP1), J2.7 (MP2), J3.1, PS1.13 (-Vo), Q1.2 (E), R6.1, R10.2, R11.1, SW1.1, SW2.1, SW3.1, TP4.1 (1_1), U1.1 (GND), U2.0 (EH), U2.A1 (GND), U2.A12 (GND), U2.B1 (GND), U2.B12 (GND), U3.1 (~OE), U3.3 (GND), U4.1 (GND), U4.2 (GND), U4.11 (GND), U4.14 (GND), U4.36 (GND), U4.37 (GND), U4.38 (GND), U4.39 (GND), U4.40 (GND), U4.41 (GND), U4.42 (GND), U4.43 (GND), U4.44 (GND), U4.45 (GND), U4.46 (GND), U4.47 (GND), U4.48 (GND), U4.49 (GND), U4.50 (GND), U4.51 (GND), U4.52 (GND), U4.53 (GND)
unnamed: D1.2 (A), K1.2 (COIL_2), Q1.3 (C)
unnamed: D2.2 (A2), D4.2 (A), U2.A4 (VBUS), U2.A9 (VBUS), U2.B4 (VBUS), U2.B9 (VBUS)
unnamed: D6.4 (DIN), R20.2
unnamed: IC1.A1 (CCW), R1.2, R3.2
unnamed: IC1.B1 (CW), R2.2, R4.1
unnamed: J2.4, R14.2, R16.1
unnamed: J2.5, R13.2, R15.2
unnamed: Q1.1 (B), R7.1
unnamed: R11.2, U2.A5 (CC1)
unnamed: R10.1, U2.B5 (CC2)
unnamed: R20.1, U3.4 (Y)
unnamed: R17.1, U4.22 (IO8)

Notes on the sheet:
RGB LED
External encoder connector
Encoder
USB interface
Commission switch
Reset switch
5V to 3.3V
C10: ESP32 bypass cap
C9: WS2812B bypass cap
External switch connectors
230V power supply + toggle relay

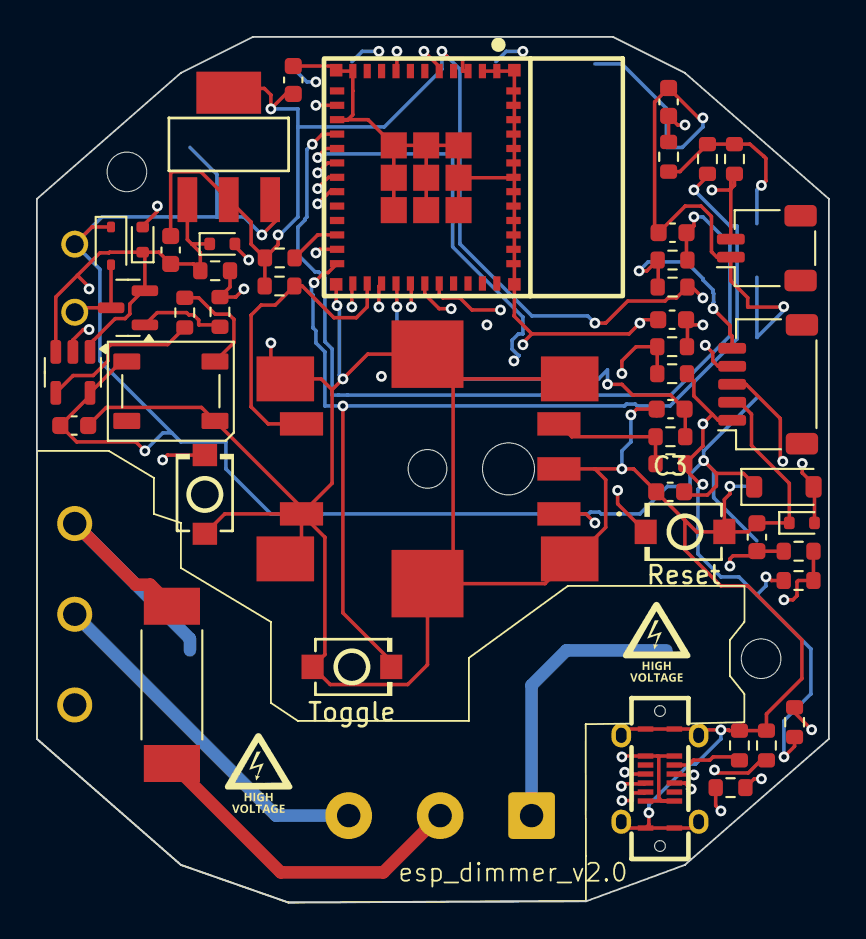
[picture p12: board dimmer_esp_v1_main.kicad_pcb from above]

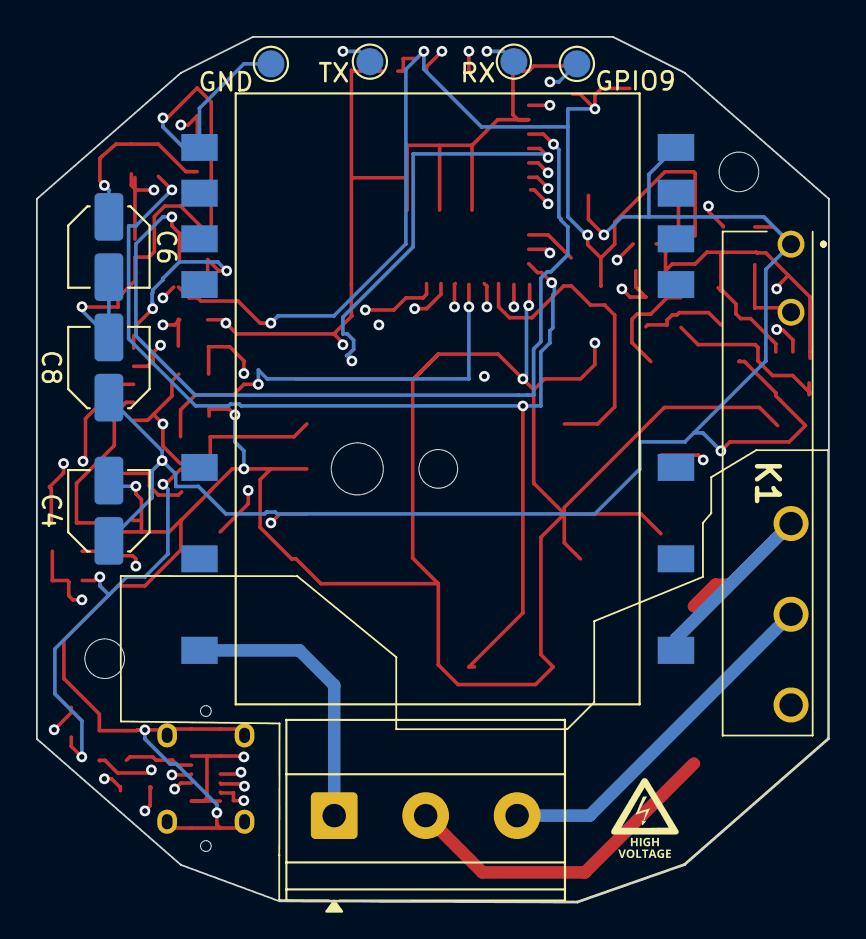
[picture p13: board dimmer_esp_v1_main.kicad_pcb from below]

Board: 4 copper layers, 44.0 x 48.1 mm, 59 parts (10 on the bottom side), 36 nets.

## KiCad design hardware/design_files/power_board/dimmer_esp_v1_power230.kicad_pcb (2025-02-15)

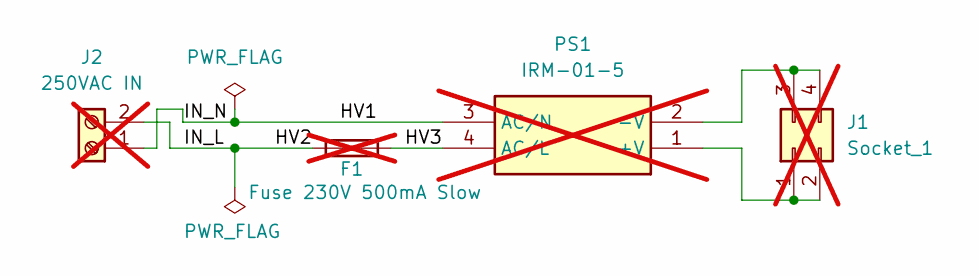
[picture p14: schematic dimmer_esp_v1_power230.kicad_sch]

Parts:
F1: Fuse 230V 500mA Slow; 0443.500DR; not fitted
J1: Socket_1; PinSocket_2x02_P2.54mm_Vertical; LCSC C780055; not fitted
J2: 250VAC IN; TerminalBlock_Phoenix_MKDS-1,5-2-5.08_1x02_P5.08mm_Horizont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; LCSC C91153; not fitted
PS1: IRM-01-5; IRM015; Mouser Part Number 709-IRM01-5; not fitted

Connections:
/HV1: J2.1, PS1.3 (AC/N)
/HV2: F1.2, J2.2
/HV3: F1.1, PS1.4 (AC/L)
unnamed: J1.1, J1.2, PS1.1 (+V)
unnamed: J1.3, J1.4, PS1.2 (-V)

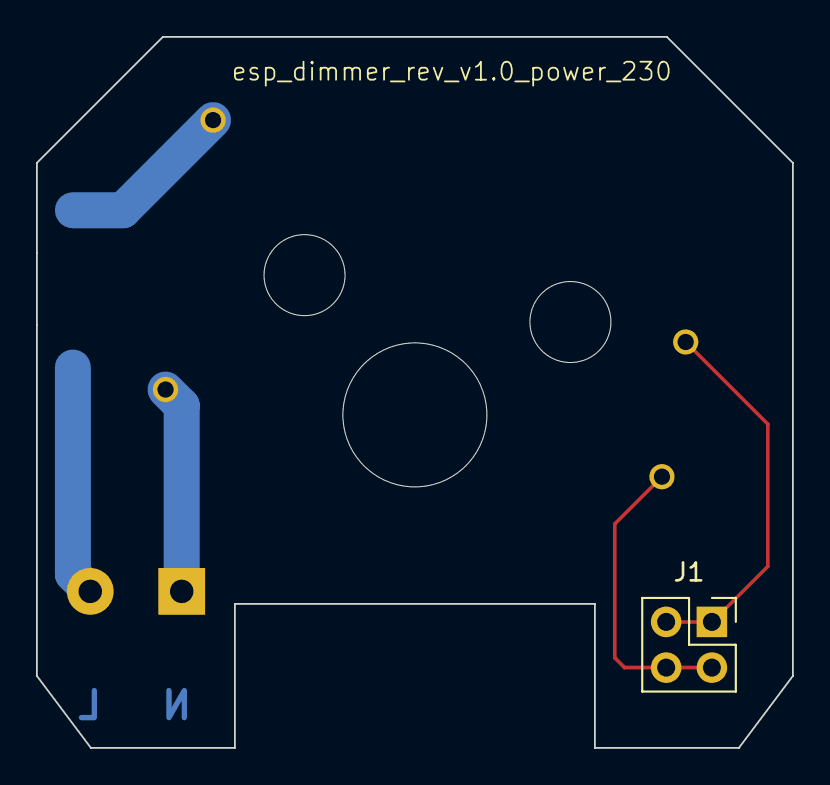
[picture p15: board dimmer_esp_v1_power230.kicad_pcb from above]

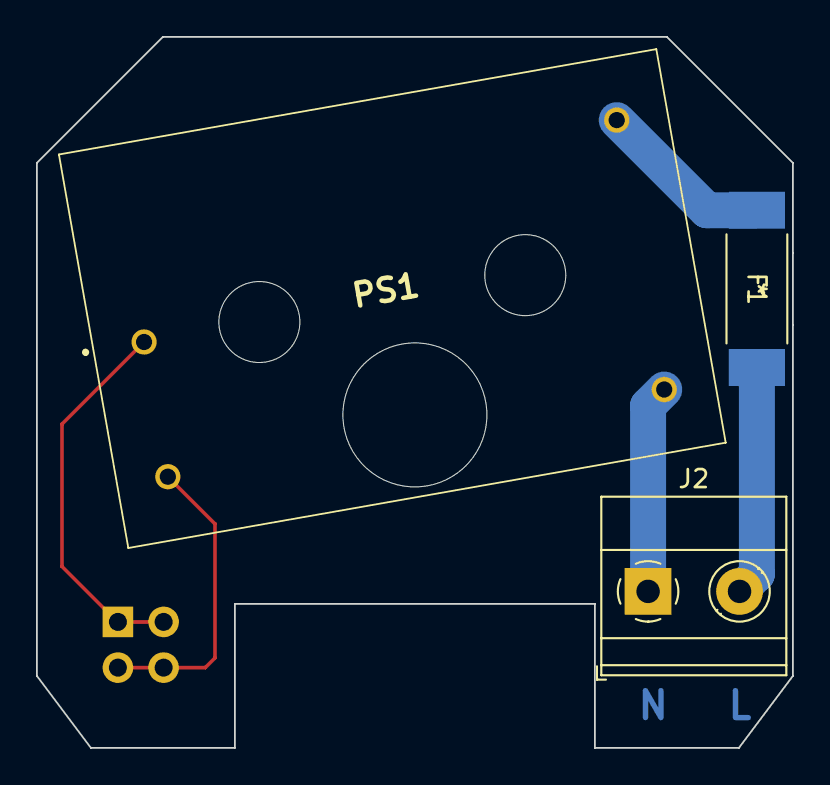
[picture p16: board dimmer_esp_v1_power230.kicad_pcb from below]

Board: 2 copper layers, 42.0 x 39.5 mm, 4 parts (3 on the bottom side), 5 nets.

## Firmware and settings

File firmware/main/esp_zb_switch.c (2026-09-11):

/*
 * SPDX-FileCopyrightText: 2021-2024 Espressif Systems (Shanghai) CO LTD
 *
 * SPDX-License-Identifier: LicenseRef-Included
 *
 * Zigbee HA_on_off_switch Example
 *
 * This example code is in the Public Domain (or CC0 licensed, at your option.)
 *
 * Unless required by applicable law or agreed to in writing, this
 * software is distributed on an "AS IS" BASIS, WITHOUT WARRANTIES OR
 * CONDITIONS OF ANY KIND, either express or implied.
 */

#include "freertos/FreeRTOS.h"
#include "freertos/task.h"
#include "string.h"

#include "esp_log.h"
#include "esp_system.h"
#include "nvs_flash.h"
#include "ha/esp_zigbee_ha_standard.h"

#include "esp_zb_switch.h"
#include "device_config.h"
#include "switch_driver.h"
#include "rotary_encoder.h"
#include "led_driver.h"
#include "ota_driver.h"
#include "relay_driver.h"

#if defined ZB_ED_ROLE
#error Define ZB_COORDINATOR_ROLE in idf.py menuconfig to compile light switch source code.
#endif


static switch_func_pair_t button_func_pair[] = {
    {GPIO_INPUT_COMMISSION_SWITCH, SWITCH_COMMISION_CONTROL},
    {GPIO_INPUT_IO_TOGGLE_SWITCH, SWITCH_ONOFF_TOGGLE_CONTROL},
    {GPIO_INPUT_RELAY_SWITCH, SWITCH_RELAY_CONTROL},
    {GPIO_INPUT_EXT_ENCODER_BUTTON, SWITCH_EXT_ENCODER_BUTTON_CONTROL},
    {GPIO_INPUT_EXT_SWITCH, SWITCH_EXT_SWITCH_CONTROL},
};

static QueueHandle_t led_evt_queue = NULL;

// Set true once steering succeeds, cleared on a reset-type leave. Gates outbound
// commands so we don't fire ZCL requests into the void, and drives a clear
// "not joined" LED indication.
static volatile bool s_network_joined = false;

// Per-encoder control state. There are two physical encoders -- the on-board one
// (EP1) and the external daughterboard one (EP3) -- each with its own button and
// its own Zigbee source endpoint so they bind to lights independently. The
// button handler and the encoder task share the button+rotate state below:
// when the button is held and the encoder rotates, send color-temperature
// commands instead of brightness; when the button is released after rotation,
// suppress the toggle. Each encoder gets its own instance so the two don't
// cross-talk.
typedef struct {
    uint8_t src_endpoint;                  // Zigbee endpoint commands are sent from
    gpio_num_t pin_a;                      // encoder channel A
    gpio_num_t pin_b;                      // encoder channel B
    portMUX_TYPE mux;                      // guards the button+rotate fields below
    volatile bool button_down;
    volatile bool rotated_while_pressed;
    volatile TickType_t press_tick;
} encoder_ctrl_t;

static encoder_ctrl_t s_onboard_encoder = {
    .src_endpoint = HA_ONOFF_SWITCH_ENDPOINT,
    .pin_a = ROT_ENC_A_GPIO,
    .pin_b = ROT_ENC_B_GPIO,
    .mux = portMUX_INITIALIZER_UNLOCKED,
};

static encoder_ctrl_t s_ext_encoder = {
    .src_endpoint = HA_EXT_ENCODER_ENDPOINT,
    .pin_a = EXT_ROT_ENC_A_GPIO,
    .pin_b = EXT_ROT_ENC_B_GPIO,
    .mux = portMUX_INITIALIZER_UNLOCKED,
};

// Debounce period: ignore encoder events within this time after button press
// This prevents spurious encoder events from mechanical coupling when pressing the button
#define ENCODER_DEBOUNCE_AFTER_PRESS_MS 50

// Safety timeout: if button_down state persists longer than this, force reset
// This prevents getting stuck if a release event is somehow missed
#define BUTTON_STATE_TIMEOUT_MS 5000

// ZCL step mode values (spec section 3.10.2.3.1 / 5.2.2.3.1)
#define ZCL_STEP_MODE_UP   0x00
#define ZCL_STEP_MODE_DOWN 0x01

// The ZBOSS stack is single-threaded and not reentrant: it runs on the Zigbee
// main-loop task (esp_zb_task). Any esp_zb_* call issued from another task --
// here the button-detect task (esp_zb_buttons_handler) and the encoder task --
// races the stack's internal critical sections. That corrupts FreeRTOS's
// critical-nesting counter and trips "assert failed: vPortExitCritical
// (port_uxCriticalNesting[0] > 0)" under bursts of commands (e.g. fast rotary
// turns). Guard every cross-task stack call with the stack lock.
// NOTE: callbacks that already run in stack context (esp_zb_app_signal_handler,
// scheduler-alarm callbacks) must NOT use this -- they already hold the stack
// and re-acquiring would deadlock.
//
// The wait is bounded (not portMAX_DELAY) so that if the stack ever wedges
// while holding the lock, the button/encoder tasks drop the command instead of
// blocking forever -- a frozen UI behind drywall is worse than a lost step.
#define ZB_STACK_LOCK_TIMEOUT_MS 2000
#define ZB_LOCKED(stmt) do {                                                  \
        if (esp_zb_lock_acquire(pdMS_TO_TICKS(ZB_STACK_LOCK_TIMEOUT_MS))) {   \
            stmt;                                                             \
            esp_zb_lock_release();                                           \
        } else {                                                             \
            ESP_LOGW(TAG, "Zigbee stack lock timeout, dropped: %s", #stmt);  \
        }                                                                     \
    } while (0)

// Send a bound ZCL command, but only while we're actually on a network. Either
// way the user gets LED feedback: a white blink when the command is sent, a red
// blink when it's dropped because the device isn't joined.
#define ZB_SEND_CMD(stmt) do {                                       \
        led_state_t _fb;                                             \
        if (s_network_joined) {                                      \
            ZB_LOCKED(stmt);                                         \
            _fb = LED_COLOR_STATE_BLINK_ONCE_WHITE;                  \
        } else {                                                     \
            ESP_LOGW(TAG, "Not joined; dropped: %s", #stmt);         \
            _fb = LED_COLOR_STATE_BLINK_ONCE_RED;                    \
        }                                                            \
        xQueueSend(led_evt_queue, &_fb, 0);                          \
    } while (0)

static const char *TAG = "ESP_ZB_ON_OFF_SWITCH";

// Handle a press/hold/release event for an encoder's push-button. Shared by both
// the on-board encoder (EP1) and the external encoder (EP3); `enc` selects which
// instance's state and source endpoint to use. Mirrors the button+rotate
// interaction: short press = toggle, hold = off, and either is suppressed if the
// encoder was rotated while the button was held (that gesture is color-temp).
static void handle_encoder_button(encoder_ctrl_t *enc, switch_state_t state)
{
    #ifdef DEBUG_ENABLED
    ESP_LOGI(TAG, "handle_encoder_button ep=%d state=%d", enc->src_endpoint, state);
    #endif

    switch(state) {
        case SWITCH_PRESS_DETECTED:
            // Button pressed: record time and reset rotation flag
            taskENTER_CRITICAL(&enc->mux);
            enc->button_down = true;
            enc->rotated_while_pressed = false;
            enc->press_tick = xTaskGetTickCount();
            taskEXIT_CRITICAL(&enc->mux);
            #ifdef DEBUG_ENABLED
            ESP_LOGI(TAG, "Button down, button_down=true");
            #endif
            break;

        case SWITCH_RELEASE_DETECTED: {
            // Short press release: send toggle only if encoder didn't rotate
            bool rotated;
            taskENTER_CRITICAL(&enc->mux);
            rotated = enc->rotated_while_pressed;
            enc->button_down = false;
            enc->rotated_while_pressed = false;
            taskEXIT_CRITICAL(&enc->mux);

            if (!rotated) {
                esp_zb_zcl_on_off_cmd_t toggle_cmd_req;
                toggle_cmd_req.zcl_basic_cmd.src_endpoint = enc->src_endpoint;
                toggle_cmd_req.address_mode = ESP_ZB_APS_ADDR_MODE_DST_ADDR_ENDP_NOT_PRESENT;
                toggle_cmd_req.on_off_cmd_id = ESP_ZB_ZCL_CMD_ON_OFF_TOGGLE_ID;
                #ifdef DEBUG_ENABLED
                ESP_LOGI(TAG, "Send 'on_off toggle' command");
                #endif
                ZB_SEND_CMD(esp_zb_zcl_on_off_cmd_req(&toggle_cmd_req));
            } else {
                #ifdef DEBUG_ENABLED
                ESP_LOGI(TAG, "Toggle suppressed - encoder rotated while pressed");
                #endif
            }
            break;
        }

        case SWITCH_LONG_RELEASE_DETECTED:
        case SWITCH_HOLD_RELEASE_DETECTED: {
            // Released after any hold >=0.5s (both the 0.5-5s and >5s paths):
            // send off if the encoder didn't rotate. Handling both releases
            // removes the dead zone where a >5s hold used to do nothing.
            bool rotated;
            taskENTER_CRITICAL(&enc->mux);
            rotated = enc->rotated_while_pressed;
            enc->button_down = false;
            enc->rotated_while_pressed = false;
            taskEXIT_CRITICAL(&enc->mux);

            if (!rotated) {
                esp_zb_zcl_on_off_cmd_t off_cmd_req;
                off_cmd_req.zcl_basic_cmd.src_endpoint = enc->src_endpoint;
                off_cmd_req.address_mode = ESP_ZB_APS_ADDR_MODE_DST_ADDR_ENDP_NOT_PRESENT;
                off_cmd_req.on_off_cmd_id = ESP_ZB_ZCL_CMD_ON_OFF_OFF_ID;
                #ifdef DEBUG_ENABLED
                ESP_LOGI(TAG, "Send 'on_off off' command");
                #endif
                ZB_SEND_CMD(esp_zb_zcl_on_off_cmd_req(&off_cmd_req));
            } else {
                #ifdef DEBUG_ENABLED
                ESP_LOGI(TAG, "Off suppressed - encoder rotated while pressed");
                #endif
            }
            break;
        }

        case SWITCH_LONG_PRESS_DETECTED:
            // Long press detected (button still held): no action needed, state stays
            #ifdef DEBUG_ENABLED
            ESP_LOGI(TAG, "Long press detected, button still held");
            #endif
            break;

        case SWITCH_HOLD_DETECTED:
            // Hold detected (button still held): no action needed, state stays
            #ifdef DEBUG_ENABLED
            ESP_LOGI(TAG, "Hold detected, button still held");
            #endif
            break;

        default:
            // Safety: any unknown state should clear button_down to prevent stuck state
            taskENTER_CRITICAL(&enc->mux);
            enc->button_down = false;
            enc->rotated_while_pressed = false;
            taskEXIT_CRITICAL(&enc->mux);
            #ifdef DEBUG_ENABLED
            ESP_LOGI(TAG, "Unknown state %d, clearing button state", state);
            #endif
            break;
    }
}

static void esp_zb_buttons_handler(switch_func_pair_t *button_func_pair, switch_state_t state)
{
    if (button_func_pair->func == SWITCH_ONOFF_TOGGLE_CONTROL) {
        handle_encoder_button(&s_onboard_encoder, state);
    }

    if (button_func_pair->func == SWITCH_EXT_ENCODER_BUTTON_CONTROL) {
        handle_encoder_button(&s_ext_encoder, state);
    }

    if (button_func_pair->func == SWITCH_EXT_SWITCH_CONTROL) {
        // External plain wall switch on EP4: toggle the bound target on each
        // press. No level/color gesture -- it's a one-contact switch.
        if (state == SWITCH_RELEASE_DETECTED) {
            esp_zb_zcl_on_off_cmd_t toggle_cmd_req;
            toggle_cmd_req.zcl_basic_cmd.src_endpoint = HA_EXT_SWITCH_ENDPOINT;
            toggle_cmd_req.address_mode = ESP_ZB_APS_ADDR_MODE_DST_ADDR_ENDP_NOT_PRESENT;
            toggle_cmd_req.on_off_cmd_id = ESP_ZB_ZCL_CMD_ON_OFF_TOGGLE_ID;
            #ifdef DEBUG_ENABLED
            ESP_LOGI(TAG, "Ext switch: send 'on_off toggle' command");
            #endif
            ZB_SEND_CMD(esp_zb_zcl_on_off_cmd_req(&toggle_cmd_req));
        }
    }

    if (button_func_pair->func == SWITCH_COMMISION_CONTROL) {

        switch(state) {
            case SWITCH_RELEASE_DETECTED:
                // Short press: trigger network steering (rejoin/find new network)
                ESP_LOGI(TAG, "Commission button: start network steering");
                ZB_LOCKED(esp_zb_bdb_start_top_level_commissioning(ESP_ZB_BDB_MODE_NETWORK_STEERING));
                {
                    led_state_t led_state = LED_COLOR_STATE_BLINK_ONCE_YELLOW;
                    xQueueSend(led_evt_queue, &led_state, 0);
                }
                break;
            case SWITCH_LONG_PRESS_DETECTED:
                // Held past 0.5s: warn (blinking yellow) that continuing to ~5s
                // will factory-reset, so it can't happen silently/accidentally.
                ESP_LOGW(TAG, "Hold to factory reset (release now to abort)...");
                {
                    led_state_t led_state = LED_COLOR_STATE_BLINK_YELLOW;
                    xQueueSend(led_evt_queue, &led_state, 0);
                }
                break;
            case SWITCH_LONG_RELEASE_DETECTED:
                // Released during the warning window: abort, no reset, no steer.
                ESP_LOGI(TAG, "Factory reset aborted");
                {
                    led_state_t led_state = s_network_joined ? LED_COLOR_STATE_OFF
                                                             : LED_COLOR_STATE_WARN_RED;
                    xQueueSend(led_evt_queue, &led_state, 0);
                }
                break;
            case SWITCH_HOLD_DETECTED:
                // Held to 5s: factory reset
                ESP_LOGW(TAG, "Commission button held: factory reset");
                {
                    led_state_t led_state = LED_COLOR_STATE_BLINK_RED;
                    xQueueSend(led_evt_queue, &led_state, 0);
                }
                ZB_LOCKED(esp_zb_factory_reset());
                break;
            default:
                break;
        }
    }

    if (button_func_pair->func == SWITCH_RELAY_CONTROL) {
        // Dedicated relay button. Works regardless of network state (this is the
        // local/offline cut-off), and we reflect the new outlet state back to the
        // coordinator's on/off attribute so HA stays in sync.
        if (state == SWITCH_RELEASE_DETECTED) {
            bool outlet_on = !relay_get();
            relay_set(outlet_on);
            relay_remember();   // persist for the "previous" power-on behavior
            uint8_t attr_val = outlet_on ? 1 : 0;
            ZB_LOCKED(esp_zb_zcl_set_attribute_val(HA_RELAY_ENDPOINT,
                      ESP_ZB_ZCL_CLUSTER_ID_ON_OFF, ESP_ZB_ZCL_CLUSTER_SERVER_ROLE,
                      ESP_ZB_ZCL_ATTR_ON_OFF_ON_OFF_ID, &attr_val, false));
            ESP_LOGI(TAG, "Relay button: outlet %s", outlet_on ? "POWERED" : "CUT");
            led_state_t led = LED_COLOR_STATE_BLINK_ONCE_BLUE;  // distinct from light commands (white)
            xQueueSend(led_evt_queue, &led, 0);
        }
    }
}

static void bdb_start_top_level_commissioning_cb(uint8_t mode_mask)
{
    /* Don't ESP_ERROR_CHECK here: a re-steer can legitimately return an error
     * (e.g. one is already in progress). Aborting would reboot the device. */
    esp_err_t err = esp_zb_bdb_start_top_level_commissioning(mode_mask);
    if (err != ESP_OK) {
        ESP_LOGW(TAG, "start_top_level_commissioning(0x%x) failed: %s", mode_mask, esp_err_to_name(err));
    }
}
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
void app_main(void) {
    /* Put the 230V relay in a known-OFF state as the very first thing at boot. */
    relay_init();

    esp_zb_platform_config_t config = {
        .radio_config = ESP_ZB_DEFAULT_RADIO_CONFIG(),
        .host_config = ESP_ZB_DEFAULT_HOST_CONFIG(),
    };
    ESP_ERROR_CHECK(nvs_flash_init());
    /* NVS is up now: apply the persisted relay power-on behavior. */
    relay_apply_startup();
    ESP_ERROR_CHECK(esp_zb_platform_config(&config));

    // create queue to pass LED state events
    led_evt_queue = xQueueCreate(5, sizeof(led_state_t));
    if ( led_evt_queue == 0) {
        // Wall-installed device: a half-initialized state is unrecoverable and
        // there is no one to power-cycle it, so reboot and let init retry.
        ESP_LOGE(TAG, "Queue for LED events was not created, rebooting");
        esp_restart();
    }

    // create light strip
    setup_led_strip(led_evt_queue);
    led_state_t led_state_init = LED_COLOR_STATE_WARN_RED;
    xQueueSend(led_evt_queue, &led_state_init, 0);

    if (!switch_driver_init(button_func_pair, PAIR_SIZE(button_func_pair), esp_zb_buttons_handler)) {
        ESP_LOGE(TAG, "Switch driver init failed, rebooting");
        esp_restart();
    }
    // Zigbee task runs the stack/radio timers; it must not be starved by the
    // higher-priority UI tasks (button=10, LED=6, encoder=5) under a fast
    // encoder burst, so give it priority 5 and extra stack headroom.
    if (xTaskCreate(esp_zb_task, "Zigbee_main", 6144, NULL, 5, NULL) != pdPASS) {
        ESP_LOGE(TAG, "Failed to create Zigbee task, rebooting");
        esp_restart();
    }
    if (xTaskCreate(encoder_task, "Encoder_main", 4096, &s_onboard_encoder, 5, NULL) != pdPASS) {
        ESP_LOGE(TAG, "Failed to create encoder task, rebooting");
        esp_restart();
    }
    // Second encoder instance for the external daughterboard (EP3). If no board
    // is wired in, its A/B inputs idle high (driver enables pull-ups) and it
    // simply never produces events.
    if (xTaskCreate(encoder_task, "Encoder_ext", 4096, &s_ext_encoder, 5, NULL) != pdPASS) {
        ESP_LOGE(TAG, "Failed to create external encoder task, rebooting");
        esp_restart();
    }
}

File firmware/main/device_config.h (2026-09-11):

#pragma once

#ifdef __cplusplus
extern "C" {
#endif

#include "esp_zigbee_core.h"

// Debug flag
// #define DEBUG_ENABLED 0

/* LED config ======================================================================== */
#define LED_GPIO GPIO_NUM_1

/* Relay config ====================================================================== */
/* Drives Q1 (NPN) for the on-board 230V relay K1. GPIO high = relay energized.
   Moved off strapping pin GPIO15 to GPIO2 on the rewired board. */
#define RELAY_GPIO GPIO_NUM_2

/* Button config ===================================================================== */
/* Moved off GPIO9 (a strapping/boot pin): holding it at power-up forced serial
   download mode and the app would not start. GPIO23 is a plain, non-strapping
   GPIO. Wiring is unchanged: button to GND, external pull-up to 3.3V, active-low. */
#define GPIO_INPUT_COMMISSION_SWITCH  GPIO_NUM_23

/* Dedicated button to toggle the local 230V relay (works without a coordinator). */
#define GPIO_INPUT_RELAY_SWITCH       GPIO_NUM_18

/* Encoder config ==================================================================== */
#define GPIO_INPUT_IO_TOGGLE_SWITCH  GPIO_NUM_20

#define ROT_ENC_A_GPIO GPIO_NUM_21
#define ROT_ENC_B_GPIO GPIO_NUM_22

#define ENABLE_HALF_STEPS true  // Set to true to enable tracking of rotary encoder at half step resolution
#define RESET_AT          0      // Set to a positive non-zero number to reset the position if this value is exceeded
#define FLIP_DIRECTION    true   // Set to true to reverse the clockwise/counterclockwise sense

/* External daughterboard ports ====================================================== */
/* Two pin headers brought out so the in-wall module can drive a second control
   surface: an external rotary encoder (a second dimmer) and/or a plain wall
   switch. Both are always exposed as Zigbee endpoints (3 and 4); if nothing is
   wired in, the inputs idle high (internal pull-ups) and simply never fire, so
   the endpoints just stay unbound and unused.

   External encoder port: A, B, push-button, plus GND and 3.3V. */
#define EXT_ROT_ENC_A_GPIO            GPIO_NUM_6
#define EXT_ROT_ENC_B_GPIO            GPIO_NUM_7
#define GPIO_INPUT_EXT_ENCODER_BUTTON GPIO_NUM_19

/* External switch port: a single contact to GND (active-low). */
#define GPIO_INPUT_EXT_SWITCH         GPIO_NUM_14

/* Zigbee configuration ============================================================== */
#define MAX_CHILDREN                    10          /* the max amount of connected devices */
#define INSTALLCODE_POLICY_ENABLE       false       /* false: join with the default TC link key (what zigbee2mqtt/ZHA use by default) */
#define HA_ONOFF_SWITCH_ENDPOINT        1           /* the rotary/button controller endpoint */
#define HA_RELAY_ENDPOINT               2           /* on/off server endpoint for the local 230V relay */
#define HA_EXT_ENCODER_ENDPOINT         3           /* external encoder daughterboard (second dimmer) controller */
#define HA_EXT_SWITCH_ENDPOINT          4           /* external wall switch (simple on/off) controller */
#define ESP_ZB_PRIMARY_CHANNEL_MASK     ESP_ZB_TRANSCEIVER_ALL_CHANNELS_MASK  /* Zigbee primary channel mask use in the example */

#define ESP_ZB_ZC_CONFIG()                                                              \
    {                                                                                   \
        .esp_zb_role = ESP_ZB_DEVICE_TYPE_ROUTER,                                       \
        .install_code_policy = INSTALLCODE_POLICY_ENABLE,                               \
        .nwk_cfg.zczr_cfg = {                                                           \
            .max_children = MAX_CHILDREN,                                               \
        },                                                                              \
    }

#define ESP_ZB_DEFAULT_RADIO_CONFIG()                           \
    {                                                           \
        .radio_mode = ZB_RADIO_MODE_NATIVE,                     \
    }

#define ESP_ZB_DEFAULT_HOST_CONFIG()                            \
    {                                                           \
        .host_connection_mode = ZB_HOST_CONNECTION_MODE_NONE,   \
    }

void configure_device(void);

#ifdef __cplusplus
} // extern "C"
#endif

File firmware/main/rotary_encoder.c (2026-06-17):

/*
 * Copyright (c) 2019 David Antliff
 * Copyright 2011 Ben Buxton
 *
 * This file is part of the esp32-rotary-encoder component.
 *
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
 * You should have received a copy of the GNU General Public License
 * along with esp32-rotary-encoder.  If not, see <https://www.gnu.org/licenses/>.
 */

/**
 * @file rotary_encoder.c
 * @brief Driver implementation for the ESP32-compatible Incremental Rotary Encoder component.
 *
 * Based on https://github.com/buxtronix/arduino/tree/master/libraries/Rotary
 * Original header follows:
 *
 * Rotary encoder handler for arduino. v1.1
 *
 * Copyright 2011 Ben Buxton. Licenced under the GNU GPL Version 3.
 * Contact: bb@cactii.net
 *
 * A typical mechanical rotary encoder emits a two bit gray code
 * on 3 output pins. Every step in the output (often accompanied
 * by a physical 'click') generates a specific sequence of output
 * codes on the pins.
 *
 * There are 3 pins used for the rotary encoding - one common and
 * two 'bit' pins.
 *
 * The following is the typical sequence of code on the output when
 * moving from one step to the next:
 *
 *   Position   Bit1   Bit2
 *   ----------------------
 *     Step1     0      0
 *      1/4      1      0
 *      1/2      1      1
 *      3/4      0      1
 *     Step2     0      0
 *
 * From this table, we can see that when moving from one 'click' to
 * the next, there are 4 changes in the output code.
 *
 * - From an initial 0 - 0, Bit1 goes high, Bit0 stays low.
 * - Then both bits are high, halfway through the step.
 * - Then Bit1 goes low, but Bit2 stays high.
 * - Finally at the end of the step, both bits return to 0.
 *
 * Detecting the direction is easy - the table simply goes in the other
 * direction (read up instead of down).
 *
 * To decode this, we use a simple state machine. Every time the output
 * code changes, it follows state, until finally a full steps worth of
 * code is received (in the correct order). At the final 0-0, it returns
 * a value indicating a step in one direction or the other.
 *
 * It's also possible to use 'half-step' mode. This just emits an event
 * at both the 0-0 and 1-1 positions. This might be useful for some
 * encoders where you want to detect all positions.
 *
 * If an invalid state happens (for example we go from '0-1' straight
 * to '1-0'), the state machine resets to the start until 0-0 and the
 * next valid codes occur.
 *
 * The biggest advantage of using a state machine over other algorithms
 * is that this has inherent debounce built in. Other algorithms emit spurious
 * output with switch bounce, but this one will simply flip between
 * sub-states until the bounce settles, then continue along the state
 * machine.
 * A side effect of debounce is that fast rotations can cause steps to
 * be skipped. By not requiring debounce, fast rotations can be accurately
 * measured.
 * Another advantage is the ability to properly handle bad state, such
 * as due to EMI, etc.
 * It is also a lot simpler than others - a static state table and less
 * than 10 lines of logic.
 */

#include "rotary_encoder.h"

#include "esp_attr.h"
#include "esp_log.h"
#include "driver/gpio.h"

#define TAG "rotary_encoder"

//#define ROTARY_ENCODER_DEBUG

// Use a single-item queue so that the last value can be easily overwritten by the interrupt handler
#define EVENT_QUEUE_LENGTH 1

#define TABLE_ROWS 7

#define DIR_NONE 0x0   // No complete step yet.
#define DIR_CW   0x10  // Clockwise step.
#define DIR_CCW  0x20  // Anti-clockwise step.

// Create the half-step state table (emits a code at 00 and 11)
#define R_START       0x0
#define H_CCW_BEGIN   0x1
#define H_CW_BEGIN    0x2
#define H_START_M     0x3
#define H_CW_BEGIN_M  0x4
#define H_CCW_BEGIN_M 0x5

// Kept in DRAM so the IRAM ISR can read it while flash cache is disabled
// (e.g. during Zigbee network-state flash writes).
static DRAM_ATTR const uint8_t _ttable_half[TABLE_ROWS][TABLE_COLS] = {
    // 00                  01              10            11                   // BA
    {H_START_M,            H_CW_BEGIN,     H_CCW_BEGIN,  R_START},            // R_START (00)
    {H_START_M | DIR_CCW,  R_START,        H_CCW_BEGIN,  R_START},            // H_CCW_BEGIN
    {H_START_M | DIR_CW,   H_CW_BEGIN,     R_START,      R_START},            // H_CW_BEGIN
    {H_START_M,            H_CCW_BEGIN_M,  H_CW_BEGIN_M, R_START},            // H_START_M (11)
    {H_START_M,            H_START_M,      H_CW_BEGIN_M, R_START | DIR_CW},   // H_CW_BEGIN_M
    {H_START_M,            H_CCW_BEGIN_M,  H_START_M,    R_START | DIR_CCW},  // H_CCW_BEGIN_M
};

// Create the full-step state table (emits a code at 00 only)
#  define F_CW_FINAL  0x1
#  define F_CW_BEGIN  0x2
#  define F_CW_NEXT   0x3
#  define F_CCW_BEGIN 0x4
#  define F_CCW_FINAL 0x5
#  define F_CCW_NEXT  0x6

static DRAM_ATTR const uint8_t _ttable_full[TABLE_ROWS][TABLE_COLS] = {
    // 00        01           10           11                  // BA
    {R_START,    F_CW_BEGIN,  F_CCW_BEGIN, R_START},           // R_START
    {F_CW_NEXT,  R_START,     F_CW_FINAL,  R_START | DIR_CW},  // F_CW_FINAL
    {F_CW_NEXT,  F_CW_BEGIN,  R_START,     R_START},           // F_CW_BEGIN
    {F_CW_NEXT,  F_CW_BEGIN,  F_CW_FINAL,  R_START},           // F_CW_NEXT
    {F_CCW_NEXT, R_START,     F_CCW_BEGIN, R_START},           // F_CCW_BEGIN
    {F_CCW_NEXT, F_CCW_FINAL, R_START,     R_START | DIR_CCW}, // F_CCW_FINAL
    {F_CCW_NEXT, F_CCW_FINAL, F_CCW_BEGIN, R_START},           // F_CCW_NEXT
};

static IRAM_ATTR uint8_t _process(rotary_encoder_info_t * info)
{
    uint8_t event = 0;
    if (info != NULL)
    {
        // Get state of input pins.
        uint8_t pin_state = (gpio_get_level(info->pin_b) << 1) | gpio_get_level(info->pin_a);

        // Determine new state from the pins and state table.
#ifdef ROTARY_ENCODER_DEBUG
        uint8_t old_state = info->table_state;
#endif
        info->table_state = info->table[info->table_state & 0xf][pin_state];

        // Return emit bits, i.e. the generated event.
        event = info->table_state & 0x30;
#ifdef ROTARY_ENCODER_DEBUG
        ESP_EARLY_LOGD(TAG, "BA %d%d, state 0x%02x, new state 0x%02x, event 0x%02x",
                       pin_state >> 1, pin_state & 1, old_state, info->table_state, event);
#endif
    }
    return event;
}
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

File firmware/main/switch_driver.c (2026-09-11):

/*
 * SPDX-FileCopyrightText: 2021-2023 Espressif Systems (Shanghai) CO LTD
 *
 * SPDX-License-Identifier: LicenseRef-Included
 *
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
 * 3. Neither the name of the copyright holder nor the names of its contributors
 *    may be used to endorse or promote products derived from this software without
 *    specific prior written permission.
 *
 * 4. Any software provided in binary form under this license must not be reverse
 *    engineered, decompiled, modified and/or disassembled.
 *
 * THIS SOFTWARE IS PROVIDED BY THE COPYRIGHT HOLDERS AND CONTRIBUTORS "AS IS"
 * AND ANY EXPRESS OR IMPLIED WARRANTIES, INCLUDING, BUT NOT LIMITED TO, THE
 * IMPLIED WARRANTIES OF MERCHANTABILITY AND FITNESS FOR A PARTICULAR PURPOSE
 * ARE DISCLAIMED. IN NO EVENT SHALL THE COPYRIGHT HOLDER OR CONTRIBUTORS BE
 * LIABLE FOR ANY DIRECT, INDIRECT, INCIDENTAL, SPECIAL, EXEMPLARY, OR
 * CONSEQUENTIAL DAMAGES (INCLUDING, BUT NOT LIMITED TO, PROCUREMENT OF
 * SUBSTITUTE GOODS OR SERVICES; LOSS OF USE, DATA, OR PROFITS; OR BUSINESS
 * INTERRUPTION) HOWEVER CAUSED AND ON ANY THEORY OF LIABILITY, WHETHER IN
 * CONTRACT, STRICT LIABILITY, OR TORT (INCLUDING NEGLIGENCE OR OTHERWISE)
 * ARISING IN ANY WAY OUT OF THE USE OF THIS SOFTWARE, EVEN IF ADVISED OF THE
 * POSSIBILITY OF SUCH DAMAGE.
 */

#include "esp_log.h"
#include "esp_timer.h"
#include "esp_intr_alloc.h"
#include "freertos/FreeRTOS.h"
#include "freertos/task.h"
#include "freertos/queue.h"
#include "switch_driver.h"
#include "device_config.h"

/**
 * @brief:
 * This example code shows how to configure light switch with attribute as well as button switch handler.
 *
 * @note:
   Currently only support toggle switch functionality available
 *
 * @note:
 * For other possible switch functions (on/off,level up/down,step up/down). User need to implement and create them by themselves
 */

static QueueHandle_t gpio_evt_queue = NULL;
/* button function pair, should be defined in switch example source file */
static switch_func_pair_t *switch_func_pair = NULL;
/* call back function pointer */
static esp_switch_callback_t func_ptr = NULL;
/* which button is pressed */
static uint8_t switch_num = 0;
static const char *TAG = "ESP_ZB_SWITCH";

static void IRAM_ATTR gpio_isr_handler(void *arg)
{
    if (gpio_evt_queue != NULL) {
        xQueueSendFromISR(gpio_evt_queue, (switch_func_pair_t *)arg, NULL);
    }
}

/**
 * @brief Tasks for checking the button event and debounce the switch state
 *
 * @param arg      Unused value.
 */
static void switch_driver_button_detected(void *arg)
{
    gpio_num_t io_num = GPIO_NUM_NC;
    switch_func_pair_t button_func_pair;
    static switch_state_t switch_state = SWITCH_IDLE;
    bool evt_flag = false;
    uint32_t last_value_time = 0;
    bool last_value = false;
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

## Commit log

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2024-11-22 Add Kicad source files for main PCB
    [dimmer_esp_v1_main.kicad_pcb, dimmer_esp_v1_main.kicad_sch]
2024-11-22 Add Kicad source files for power PCB
    [dimmer_esp_v1_power230.kicad_pcb, dimmer_esp_v1_power230.kicad_sch]
2024-11-22 Add initial test for converting the enclosure fab script to openSCAD
    [enclosure.scad]
2024-11-24 Remove unused second page from schematics
    [dimmer_esp_v1_main.kicad_sch, dimmer_esp_v1_power230.kicad_sch]
2024-11-25 Add initial openSCAD for enclosure
    [dimmer_esp_v1_4_power230.step, enclosure.scad]
2025-01-08 Finish initial version of enclosure
    [enclosure.scad]
2025-02-15 Add current firmware code from different local git repo
    [partitions.csv]
2025-02-15 Enclosure: Minor adjustments (add little pusher to flap above front button)
    [enclosure.scad]
2025-05-31 Save as kicad 9.0.2, update libraries
    [dimmer_esp_v1_main.kicad_pcb, dimmer_esp_v1_main.kicad_sch]
2025-06-02 Add components, version with relay, needs re-layout of tracks
    [dimmer_esp_v1_main.kicad_pcb, dimmer_esp_v1_main.kicad_sch]
2025-06-03 Adapt pin header
    [dimmer_esp_v1_main.kicad_pcb]
2025-06-03 Add toggle circuit, arrange components on PCB
    [dimmer_esp_v1_main.kicad_pcb, dimmer_esp_v1_main.kicad_sch]
2025-06-06 Wired everything up
    [dimmer_esp_v1_main.kicad_pcb]
2025-06-06 Add circuit for external encoder
    [dimmer_esp_v1_main.kicad_pcb, dimmer_esp_v1_main.kicad_sch]
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2025-06-07 Add correct relay
    [dimmer_esp_v1_main.kicad_pcb, dimmer_esp_v1_main.kicad_sch]
2025-06-07 Add correct USB, fix button layout
    [dimmer_esp_v1_main.kicad_pcb, dimmer_esp_v1_main.kicad_sch]
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2025-09-15 Fix trace before remove debug interface
    [dimmer_esp_v1_main.kicad_pcb]
2025-09-15 Remove debug interface, two JST connectors, replace toggle circuit with using microcontroller
    [dimmer_esp_v1_main.kicad_sch]
2025-10-03 Add new openScad file for ESP version enclosure
    [enclosure_esp.scad]
2025-10-03 Finish holes for power connector and buttons
    [enclosure_esp.scad]
2025-10-03 Rework PCB, switch to bigger LDO, fix distance between high and low voltage
    [dimmer_esp_v1_main.kicad_pcb, dimmer_esp_v1_main.kicad_sch]
2025-10-20 Slight adjustments to fit actual hardware
    [enclosure_esp.scad]
2025-10-20 Prevent button up when encoder was rotated after button down
    [esp_zb_switch.c]
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2025-10-22 Enclosure: Adjustments to make USB fit and screw connectors more robust
    [enclosure_esp.scad]
2025-10-22 Enclosure: Add missing reference files (board outline and STL)
    [dimmer_esp_v2_main.stl]
2025-10-27 Enclosure: Fix missing holes to access screws of 230V terminal
    [enclosure_esp.scad]
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2025-11-11 Replace button queue with boolean flag
    [esp_zb_switch.c]
2025-11-12 Fix led_driver
2026-01-12 Hardware: Add pull-down to GPIO15 to ensure JTAG via USB works
    [dimmer_esp_v1_main.kicad_pcb, dimmer_esp_v1_main.kicad_sch]
2026-01-27 Firmware: Fix minor issues
    [device_config.h, led_driver.c, switch_driver.c]
2026-01-27 Firmware: Fix button handling - hold & rotate
    [device_config.h, esp_zb_switch.c]
2026-04-12 Firmware: Fix race condition in switch_driver_init
    Set func_ptr callback before starting GPIO init, which creates the
    button detection task and enables interrupts. Previously, a button press
    between init and callback assignment would dereference a NULL func_ptr.
    [switch_driver.c]
2026-04-12 Firmware: Fix FLIP_DIRECTION always being active
    Changed #ifdef to #if so that FLIP_DIRECTION=false is correctly
    evaluated as false. #ifdef only checks if the macro is defined,
    not its value, so the encoder direction was always flipped.
    [esp_zb_switch.c]
2026-04-12 Firmware: Retry network steering on failure
    Re-enable the scheduler alarm to retry network steering 1 second after
    a failure. Without this, the device stays in a RED LED state with no
    way to join a network other than rebooting.
    [esp_zb_switch.c]
2026-04-12 Firmware: Allow one-shot LED blinks to retrigger
    One-shot blink events (e.g. white pulse on encoder rotation) were
    silently dropped when the same state was requested again, because
    the dedup check skipped processing. Now one-shot events always
    retrigger, giving proper visual feedback during rapid rotation.
    [led_driver.c]
2026-04-12 Firmware: Add vTaskDelay to button debounce loops
    The debounce continue-paths in the button state machine had no delay,
    causing 100% CPU usage in a tight polling loop until the signal
    settled. Add 10ms delays matching the existing post-transition delay.
    [switch_driver.c]
2026-04-12 Firmware: Implement commission button for steering and factory reset
    Short press on GPIO 9 triggers network steering (yellow blink feedback).
    Hold for 5 seconds triggers factory reset (red blink feedback). Without
    this, there was no way to re-pair or reset the device without reflashing.
    [esp_zb_switch.c]
2026-04-12 Firmware: Replace magic numbers for ZCL step modes
    Define ZCL_STEP_MODE_UP/DOWN constants and use them instead of raw
    0/1 values in level and color step commands for readability.
    [esp_zb_switch.c]
2026-04-12 Firmware: Fix sw_build_version and register it in basic cluster
    The length byte was 9 but the intended string "20251019T1" is 10 chars,
    and the 'T' was missing from the character array. Also register the
    attribute in the ZCL basic cluster so it's actually reported.
    [device_config.c]
2026-04-12 Firmware: Fix typo WATITNG -> WAITING in LED state enum
    [led_driver.c]
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2026-04-12 Firmware: Remove unused driver_initialized flag from switch driver
    The variable was set to true but never read anywhere.
2026-04-12 Firmware: Check switch_driver_init return value in app_main
    Previously the return value was ignored, so the device would continue
    running Zigbee and encoder tasks with no working buttons if GPIO
    init failed. Now abort startup early on failure.
    [esp_zb_switch.c]
2026-04-12 Firmware: Add missing includes to led_driver.h
    The header uses QueueHandle_t and uint8_t but didn't include the
    required FreeRTOS and stdint headers, relying on transitive includes
    from other translation units.
2026-04-12 Firmware: Set initial LED state via queue instead of direct call
    set_led_rgb was called from app_main while the LED task also uses it,
    creating a potential race on the led_strip handle. Use the queue to
    set the initial red warning state, consistent with all other LED usage.
2026-04-12 Hardware: Add no_connect markers on unused ESP32 GPIO pins
    Add no_connect markers on IO0 (pin 12), IO2 (pin 5), IO3 (pin 6),
    IO4 (pin 9), IO5 (pin 10), IO23 (pin 29), and pin 4 (NC) which
    were floating without explicit no_connect markers. Suppresses ERC
    warnings and documents intentionally unused pins.
    [dimmer_esp_v1_main.kicad_sch]
2026-04-12 Hardware: Populate C8 (10uF USB VBUS bulk cap)
    Remove NC marking from C8. When powered via USB only, the 5V rail
    needs local bulk capacitance for stable operation during Zigbee TX
    current peaks.
    [dimmer_esp_v1_main.kicad_sch]
2026-04-12 Hardware: Add bypass capacitors for ESP32 and WS2812B
    Add C11 (0.1uF) near the ESP32-C6 3V3 pin for local decoupling.
    Espressif recommends bypass caps close to the module to handle
    current peaks during Zigbee TX bursts.
    Add C12 (0.1uF) between WS2812B VDD and VSS as recommended by
    the WS2812B datasheet to prevent data corruption and flickering.
    [dimmer_esp_v1_main.kicad_sch]
2026-04-19 Add changes to PCB layout
    [dimmer_esp_v1_main.kicad_pcb, dimmer_esp_v1_main.kicad_sch]
2026-04-19 Remove bypass cap for LED for now (no space on PCB)
    [dimmer_esp_v1_main.kicad_pcb, dimmer_esp_v1_main.kicad_sch]
2026-04-19 Add MPN to components
    [dimmer_esp_v1_main.kicad_pcb, dimmer_esp_v1_main.kicad_sch]
2026-04-20 Upgrade KiCad to v10
    [dimmer_esp_v1_main.kicad_pcb, dimmer_esp_v1_main.kicad_sch]
2026-06-12 Firmware: clean up signal handler dead var, deprecated main-loop API, ISR-only log macro
    - Remove unused dev_annce_params in esp_zb_app_signal_handler
    - Use esp_zb_stack_main_loop() instead of deprecated esp_zb_main_loop_iteration()
    - Replace ESP_EARLY_LOGI (ISR/early-boot only) with ESP_LOGI in task context
    [esp_zb_switch.c]
2026-06-12 Firmware: reboot on critical init failure instead of hanging
    A wall-installed device cannot be manually power-cycled, so a half-
    initialized app_main (failed LED queue, switch driver, or task creation)
    would leave the unit permanently dead. Reboot via esp_restart() on any
    critical init failure and check the previously-unchecked xTaskCreate
    results so the device retries from a clean state.
    [esp_zb_switch.c]
2026-06-12 Firmware: bound Zigbee stack-lock wait to avoid UI task wedge
    ZB_LOCKED previously acquired the stack lock with portMAX_DELAY, so a
    wedged stack holding the lock would freeze the button and encoder tasks
    forever. Use a 2s bounded acquire and drop the command on timeout so the
    UI tasks stay responsive and recoverable.
    [esp_zb_switch.c]
2026-06-12 Firmware: enable task watchdog panic for self-recovery on hang
    Previously a hung task only logged a warning (TWDT panic disabled), so a
    software wedge would leave the wall-installed device frozen with no way
    to recover. Enable CONFIG_ESP_TASK_WDT_PANIC so the watchdog reboots the
    device, which then rejoins automatically.
2026-06-12 Firmware: self-heal on network loss
    Handle ESP_ZB_ZDO_SIGNAL_LEAVE and ESP_ZB_NWK_SIGNAL_NO_ACTIVE_LINKS_LEFT:
    show the waiting/disconnected LED state and restart network steering so a
    device kicked off the network rejoins automatically instead of going dark
    until someone re-pairs it.
2026-06-12 Firmware: raise Zigbee task priority and stack size
    The Zigbee stack task was the lowest-priority app task (4), below the
    button/LED/encoder tasks, so a fast encoder burst could starve the
    stack's radio/MAC timers. Bump it to priority 5 and grow the stack to
    6144 bytes for headroom (verify with uxTaskGetStackHighWaterMark).
2026-06-12 Firmware: keep GPIO ISRs in IRAM to avoid dropped edges during flash writes
    The encoder and button ISRs ran from flash, so they could not execute
    while the cache was disabled during Zigbee network-state flash writes,
    silently dropping encoder steps and button edges. Mark the encoder ISR
    and its lookup tables IRAM/DRAM, and install the GPIO ISR service with
    ESP_INTR_FLAG_IRAM (the switch ISR was already IRAM_ATTR).
    [rotary_encoder.c, switch_driver.c]
2026-06-12 Firmware: debounce only the active button's interrupt
    Servicing a button press disabled interrupts on all buttons until the
    state machine returned to idle, so e.g. a 5s commission-button hold made
    the toggle button unresponsive. Mask only the active pin and drop the
    now-unused all-pins helper.
2026-06-12 Firmware: add TODO list for deferred wall-install items
    Record hardware-blocked and larger follow-up items from the robustness
    review: move commission button off strapping pin GPIO9 (next PCB rev),
    add OTA update support, and smaller follow-ups.
2026-06-16 Hardware: Switch button pin from GPIO09 (strapping pin) to GPIO23
    [dimmer_esp_v1_main.kicad_pcb, dimmer_esp_v1_main.kicad_sch]
2026-06-16 Hardware: Rename C9 back to C8, fix tracks
    [dimmer_esp_v1_main.kicad_pcb, dimmer_esp_v1_main.kicad_sch]
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2026-06-16 Hardware: Switch relay pin from D15 (strapping pin) to D02
    [dimmer_esp_v1_main.kicad_pcb, dimmer_esp_v1_main.kicad_sch]
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2026-06-16 Firmware: use full 4MB flash and dual-OTA partition layout
    The module has 4MB flash but was configured for 2MB with a single factory
    app, so field firmware updates were impossible. Set flash size to 4MB and
    replace the factory partition with a dual-OTA layout: ota_0/ota_1 (1.5MB
    each) + otadata, preserving the zb_storage/zb_fct Zigbee NVRAM partitions.
    This is the foundation for OTA; the transport (Zigbee OTA cluster) and
    rollback health-check remain (see TODO).
    Layout change requires a full erase on reflash; the device will re-pair
    because zb_storage moved.
    [partitions.csv]
2026-06-16 Firmware: add standard Zigbee OTA Upgrade client
    Implement the ZCL OTA Upgrade cluster (client role, 0x0019) so any standard
    coordinator (zigbee2mqtt, ZHA, deCONZ) can push firmware over the air -- no
    coordinator-specific code needed.
    - ota_driver.{c,h}: OTA cluster setup + value-callback handler that strips the
    sub-element header, writes the image to the spare OTA partition via esp_ota_*,
    and reboots into it on completion. Marks the running image valid for rollback.
    - Register a core action handler to receive OTA_UPGRADE_VALUE callbacks.
    - Advertise manufacturer code / image type / file version (in ota_driver.h) that
    the served .ota header must match; bump file_version per release.
    -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
    [device_config.c, esp_zb_switch.c]
2026-06-16 Firmware: document OTA update flow; trim OTA TODO to rollback only
    Add docs/OTA.md covering the OTA identity fields, how to build a .ota image,
    and how to serve it from zigbee2mqtt/ZHA. OTA download/apply is now done; only
    rollback (auto-revert of a bad image) remains in the TODO.
2026-06-16 Firmware: enable OTA rollback gated on network rejoin
    Turn on CONFIG_BOOTLOADER_APP_ROLLBACK_ENABLE. A freshly OTA'd image now boots
    in pending-verify and is confirmed only after the device rejoins the network
    (ota_confirm_running_image() from the steering-success signal) -- proof the new
    firmware's stack and radio work. If it crashes or wedges first, the task
    watchdog reboot lets the bootloader revert to the previous image, so a bad
    update self-heals without a site visit. No-op for UART-flashed images.
    [esp_zb_switch.c]
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2026-06-16 Firmware: don't re-steer on leave-with-rejoin (fixes join failure)
    The network-loss self-heal handler restarted steering on *every* LEAVE
    signal, including the leave-with-rejoin that ZBOSS emits as a normal part
    of commissioning -- and it did so inline, colliding with the in-progress
    join ('In BDB commissioning, an error occurred ... already running') and
    breaking the join entirely.
    - Ignore ESP_ZB_NWK_LEAVE_TYPE_REJOIN leaves: the stack rejoins itself.
    - Only restart steering on a RESET leave (device removed) / no-active-links,
    and defer it via the scheduler so it can't collide with a running op.
    - Make bdb_start_top_level_commissioning_cb non-fatal (was ESP_ERROR_CHECK,
    which would re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
    [esp_zb_switch.c]
2026-06-16 Firmware: revert network-loss self-heal (caused join failures + stack assert)
    Re-steering from the LEAVE / NO_ACTIVE_LINKS_LEFT signal handlers raced the
    stack's commissioning and leave/reset state machines: it broke initial joins
    (leave-with-rejoin is a normal commissioning step) and, on a coordinator-forced
    leave-reset, the stack asserted in zdo_app.c while steering was retrying.
    Remove the self-heal cases (back to the known-good default no-op; the stack
    auto-rejoins routers on transient loss) and slow the steering retry 1s -> 3s to
    reduce in-flight commissioning calls. Keep the non-fatal re-steer callback.
    TODO: re-add self-heal safely (reboot on RESET leave) later.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
    [esp_zb_switch.c]
2026-06-16 Firmware: disable install-code policy so the device joins z2m/ZHA
    INSTALLCODE_POLICY_ENABLE=true makes the device refuse the default Trust-Center
    link key and require an install-code-derived key the coordinator would have to
    pre-register; zigbee2mqtt/ZHA join with the well-known default key by default,
    so steering kept failing on the newer SDK (1.6.8 enforces this; 1.0.9 did not).
    Set false to join with the default key, matching the Espressif HA examples.
    [device_config.h]
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2026-06-17 Firmware: single-source the version (main/version.h)
    The version lived in three hand-edited places (OTA file version, the SW Build ID
    string, the IDF app version) plus a --version arg to the packaging script, which
    is a release foot-gun: miss one and OTA silently won't offer the update or the
    reported version lies.
    Introduce main/version.h with FW_VERSION_MAJOR/MINOR/PATCH as the single source:
    - ota_driver.h derives OTA_UPGRADE_FILE_VERSION from it,
    - device_config.c builds the Basic-cluster SW Build ID string from it,
    - CMakeLists.txt sets PROJECT_VER from it (IDF app version),
    - tools/make_ota.py reads version + manufacturer/image-type from the headers, so
    packaging needs no hand-typed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
    [device_config.c]
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2026-06-17 Firmware: suppress commands when not joined + LED feedback on every send
    Track network-joined state (set on steering success, cleared only on a
    reset-type leave -- not on transient link loss, which a router rejoins on its
    own without re-signalling). Gate all outbound ZCL commands on it via a new
    ZB_SEND_CMD macro that also gives LED feedback: white blink = command sent,
    red blink = dropped because not joined. This also adds the missing LED feedback
    to the button toggle/off commands (only the encoder flashed before).
    [esp_zb_switch.c]
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2026-06-17 Firmware: fix relay NC inversion (on = outlet powered)
    The relay's NC contact carries the load, so coil de-energized (GPIO low) = NC
    closed = outlet POWERED, and energized = CUT. The previous code had it backward:
    a Zigbee 'on' energized the coil and CUT power, and the cluster defaulted to off
    while the hardware actually boots powered. Model state as 'outlet powered'
    (matching the Zigbee on/off meaning), invert the GPIO in the driver, and default
    the cluster + boot state to ON/powered.
    [device_config.c, relay_driver.c]
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2026-06-17 Firmware: warn before factory reset (no more silent 5s wipe)
    The commission button reset fired silently at 5s with no warning. Now holding
    past 0.5s blinks yellow ('hold to reset, release to abort'), 5s resets (red),
    and releasing in between aborts cleanly without resetting or re-steering.
    [esp_zb_switch.c]
2026-06-17 Firmware: fix knob-push dead zone (hold >5s now also turns off)
    Holding the knob 0.5-5s and releasing sent 'off', but holding past 5s and
    releasing did nothing -- a surprising dead zone. Handle the hold-release the
    same as the long-release so any hold >=0.5s turns off consistently.
    [esp_zb_switch.c]
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2026-06-17 docs: refresh README current-state with hardware, controls, firmware, repo layout
    Replace the stale 'need to update this README' note with a current description:
    hardware overview, the knob/button control map + LED feedback, build/flash steps
    and OTA, and the repository layout. Mark the two 'nice to have' features (push-
    rotate color temperature, on-board relay) as implemented.
2026-06-17 Firmware: bump version to 1.1.0 for release
    Release with the relay (NC fix, local GPIO18 button, configurable
    power_on_behavior), push-rotate color temperature, factory-reset warning,
    not-joined command suppression + LED feedback, and the knob-push dead-zone fix.
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2026-06-22 Firmware: invert rotary encoder direction
    CW was sending brightness down and CCW up; flip FLIP_DIRECTION so CW =
    up. Applies to both the on-board and external encoders via the shared
    encoder_task.
    [device_config.h]
2026-09-04 Enclosure: Split the base plate from thread so both can be printed with minimal support. Try to get the clearance between shaft and thread right.
    [enclosure_esp.scad]
2026-09-11 Hardware: Smaller fixes
    * Missing power flags
    * Add missing bypass cap for LED
    * Fix labels
    * Add test points for GPIO9, TX, RX, and ground
    [dimmer_esp_v1_main.kicad_pcb, dimmer_esp_v1_main.kicad_sch]
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2026-09-11 Hardware: Clean up schematics to avoid confusion

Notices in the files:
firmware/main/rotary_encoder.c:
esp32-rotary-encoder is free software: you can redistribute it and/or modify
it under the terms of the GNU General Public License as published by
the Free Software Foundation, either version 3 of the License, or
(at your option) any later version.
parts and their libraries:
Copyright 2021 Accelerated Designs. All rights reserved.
